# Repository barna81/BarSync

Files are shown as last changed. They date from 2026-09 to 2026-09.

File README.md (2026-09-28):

<picture><source media="(prefers-color-scheme: dark)" srcset="images/BarSync_logo_white.svg"><source media="(prefers-color-scheme: light)" srcset="images/BarSync_logo.svg">BarSync Logo</picture>
<p align="right">
<b>MIDI Clock Bar Counter</b><br/>
<sub><i>-Always in Time.-</i></sub>
</p>
<br clear="left"/>

*[Deutsche Version](README.de.md)*

BarSync is an ESP32-based device that receives an incoming MIDI clock and
displays bar position, beat progress, tempo, and elapsed play time on a
128×64 OLED display.

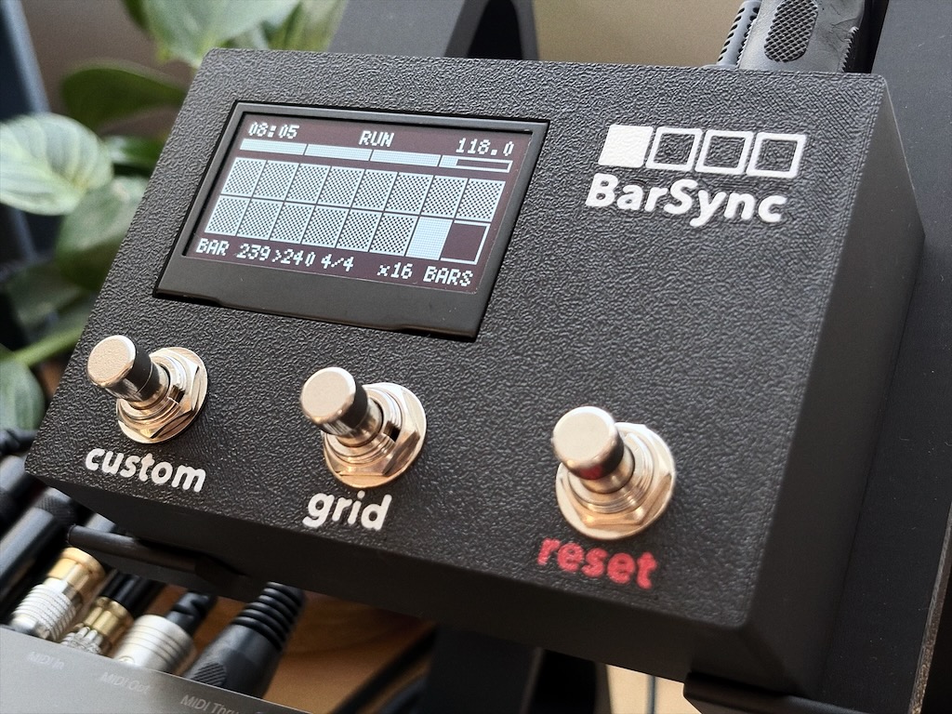
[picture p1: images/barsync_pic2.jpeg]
BarSync


## Status (as of 2026-09-22)

BarSync - Desktop version (this device) 
- Current firmware: 1.3.2  
Improvements: introduced a browser-based firmware flasher — firmware
can now be flashed straight from the browser (Chrome/Edge), no Arduino
IDE needed, see the "Flashing the Firmware" section below; no
functional firmware changes
- Firmware: 1.3.1  
    Improvements: SCROLL mode with a much clearer sense of motion (stripe
    pattern + marker halo), extended bar/playtime counter limits, grid
    counter/BPM detection now keep running seamlessly in the background,
    various button-combo bug fixes
- Firmware: 1.3.0  
    New features: Marker Editor (place your own markers on the bar grid), two grid display modes (CYCLE/SCROLL), End Bar (loop/stop/continue the count at a defined bar)
- Schematic, PCB layout (hardware rev. 1.2), and firmware finished and tested
- PCBs for self-assembly have arrived
- A matching 3D-printable enclosure is available here [`enclosure`](enclosure/)
- A solder-it-yourself kit is being considered, depending on interest

BarSync - Eurorack version (in development, not yet on GitHub)
- Code finished
- PCB layout finished and ordered
- Schematic and PCB layout to follow
- 3D-printable Eurorack frame is in development

*(Interested in the kit or the Eurorack version? Open an issue in this repo or get in touch.)*

---

## What is this?
Never miss the drop...

BarSync keeps you locked into your track's arrangement — live or in the studio. Know exactly where you stand in the bar count, so drops, breaks and builds never catch you off guard.

Since I couldn't find anything similar on the market or in the DIY scene, I built BarSync.
BarSync supports you during your live performance. During a show your hands are usually full, and it's easy to lose track of the timing. No more counting bars in your head to land the drop at the right moment: BarSync counts and visualizes the bars elapsed since a starting point you define yourself. That starting point can be the first MIDI clock signal from your sequencer, or you can reset it at any time with the reset button. This way you always know exactly which bar you're in. The visualization adapts to your needs (1-128 bars can be displayed).

## Features

- Bar/beat counter, synced to the incoming MIDI clock (24 PPQN)
- Grid progress bar (x1 to x128 bars) — overall area stays constant,
  tile size adapts accordingly
- Two grid display modes: CYCLE (repeating cycle) or SCROLL
  (continuous, with markers scrolling into view)
- Marker Editor: place your own markers on the bar grid (4 symbols) —
  for arrangement points, phrase starts, or band cues
- End Bar: automatically loop, stop, or continue the count at a
  defined bar — fixed, or at your last placed marker
- 5 selectable time signatures (2/4, 3/4, 4/4, 5/4, 7/8)
- Reset button: two stages (short = bar end, medium/hold = cycle end) — each independently configurable whether it also resets the elapsed play time (default: yes). Plus a standalone "SET 1.1" function (default custom-button role) to instantly re-anchor the beat pattern, either quantized (rounded to the nearest beat) or instant (raw tick) — selectable in the settings menu
- MIDI Monitor (Note/CC/PC/Pitch Bend log, MIDI clock and RUN/STOP graph) right on the device
- Nudge mode for manually compensating clock phase drift
- MIDI-Thru
- Standby (light sleep) on MIDI inactivity
- On-device settings menu (no app or software required)

## Operation

Quick overview — full guide in
[`docs/BarSync_Quickstart_EN.pdf`](docs/BarSync_Quickstart_EN.pdf):

| Button | Function |
|---|---|
| Custom button (short) | SET 1.1 (re-anchor beat pattern)* |
| Custom button (hold 1s) | Toggle MIDI Monitor** |
| Grid (short) | Change the number of bars shown in the grid (x1–x128) |
| Reset (short/medium) | Reset stage 1/2 |
| Custom button + Grid together | Toggle nudge mode |
| Hold Reset 1s at boot | Settings menu |

*Configurable in setup: custom button for cycling through the time signatures, or SET1.1 (default)  
**In the MIDI Monitor screen, the reset button clears the Note/CC log instead of triggering its normal reset function.

---

## Cool! How do I get one?

If you'd like to build the device yourself, see [LICENSE](LICENSE) — you'll find the corresponding firmware, schematic, and parts list here. I've also designed a PCB, whose layout is included as well. Since it's a fairly simple layout, you can also use perfboard or even a breadboard to build BarSync. Basic knowledge of the ESP32, a soldering iron, and general electronics will be helpful.

In short: the project is currently still in a full DIY stage. Depending on interest, I'm considering offering a BarSync kit. It would come with a 3D-printed enclosure, a PCB, and all the necessary electronic components ready to be assembled. All that would be left to do is soldering and flashing the ESP32.

## Building Your Own

- Full [`schematic`](hardware/kicad/BarSync/BarSync_schematic.pdf)  
- PCB layout, and Gerber files are in [`hardware/`](hardware/)  
- Full bill of materials: [`hardware/BarSync_BOM.en.md`](hardware/BarSync_BOM.en.md)  
- Electronic parts as a ready-made Reichelt cart: [reichelt.de/my/2391791](https://www.reichelt.de/my/2391791)  
- Assembly guide: [`hardware/BarSync_Aufbauanleitung.en.md`](hardware/BarSync_Aufbauanleitung.en.md)  
- 3D-printable enclosure available here: [`enclosure`](enclosure/)

<p align="center">
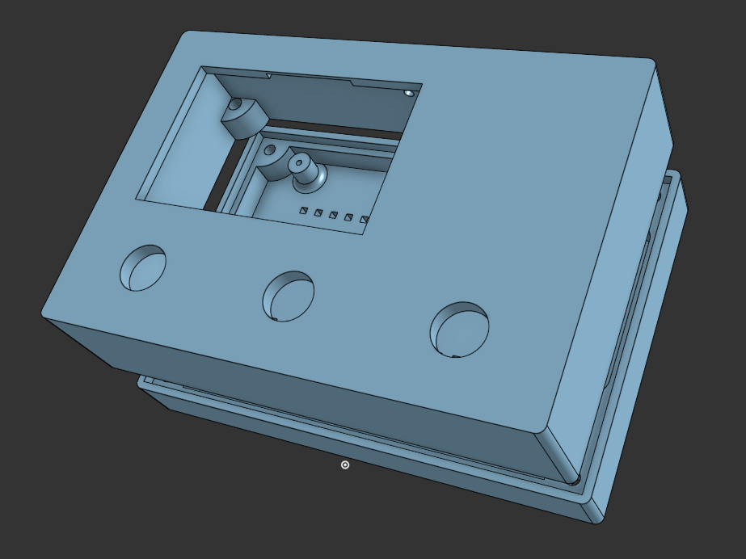
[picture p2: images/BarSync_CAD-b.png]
BarSync_CAD

</p>

## What´s inside?
First build with the new PCB!  

<p align="center">
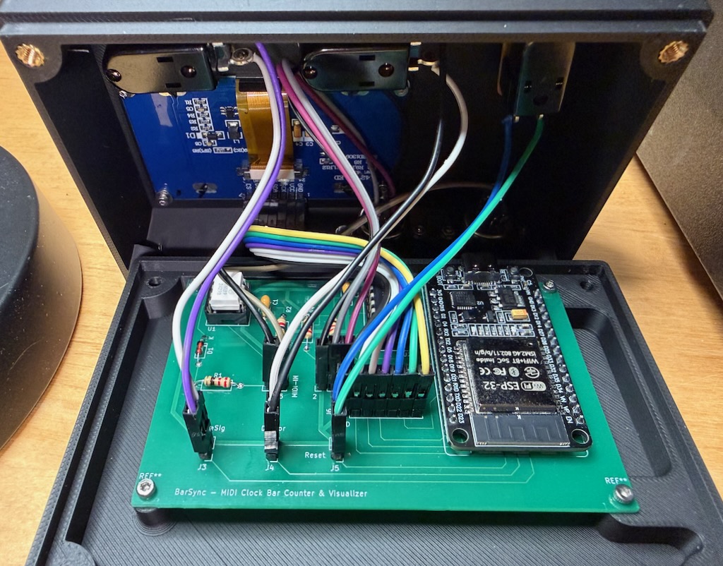
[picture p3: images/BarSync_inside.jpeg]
BarSync_inside

</p>

## Key Hardware

- ESP32 dev board (30-pin DOIT layout)
- SSD1309 OLED, 2.42", 128×64, SPI
- 3 buttons (custom, grid, reset)

## Flashing the Firmware

### 1. Web Flasher (recommended)

Right from your browser, no Arduino IDE, no driver install — works in Chrome or Edge (Windows/macOS/Linux):

**[barna81.github.io/BarSync/flash](https://barna81.github.io/BarSync/flash/)**

### 2. Manual Flashing (Arduino IDE)

For anyone who prefers to compile it themselves, or whose browser doesn't support the web flasher (e.g. Safari, Firefox). Detailed step-by-step instructions incl. USB driver install: see **Chapter 8 "Flash the Firmware"** in the [Assembly Guide](hardware/BarSync_Aufbauanleitung.en.md).

Short version:
1. Install the Arduino IDE, add ESP32 board support
2. Install libraries: [**"MIDI Library"**](https://github.com/FortySevenEffects/arduino_midi_library) (FortySevenEffects), [**"U8g2"**](https://github.com/olikraus/u8g2) (olikraus)
3. Open [`firmware/barsync.ino`](firmware/barsync.ino), select board "ESP32 Dev Module", upload

## License

This project is licensed under **CC BY-NC-SA 4.0** — see [LICENSE](LICENSE).
Free to use, modify, and share for **non-commercial** purposes, with
attribution and share-alike terms. For commercial use, please get in touch.

---

*[Deutsche Version](README.de.md)*

*Built with a lot of debugging, deep MIDI timing analysis, and an
occasional detour into building a Space Invaders clone.*

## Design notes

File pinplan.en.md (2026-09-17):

# Pin Plan — BarSync (ESP32)

*[Deutsche Version](pinplan.md)*

> **Note:** For readability, the PCB header designators (J1–J6) are
> intentionally left out here — this pin plan focuses on the signal logic
> (which signal goes where). For the mapping to the board headers, see
> [`hardware/BarSync_BOM.en.md`](hardware/BarSync_BOM.en.md) and
> [`hardware/BarSync_Aufbauanleitung.en.md`](hardware/BarSync_Aufbauanleitung.en.md).

## 1. Display — SSD1309 2.42" OLED (SPI, 128×64)

**Connection (for kit/PCB version):** The main board carries a
**7-pin header (2.54 mm pitch)** that breaks out the relevant ESP32 pins.
From the display itself, a **7-wire ribbon cable (rainbow cable) with
Dupont sockets on both ends** runs to the header on the board. This lets
the display be mounted mechanically independent of the main board in the
enclosure window (at a different position/height), without any soldering
on the display itself — both ends simply plug in.

| Display Pin | ESP32 Pin | GPIO | Cable Color (ribbon cable) |
|---|---|---|---|
| GND | GND | – | |
| VCC | 3V3 | – | |
| SCK / D0 / CLK | GPIO18 | 18 | |
| SDA / D1 / MOSI | GPIO23 | 23 | |
| RES / RST | GPIO4 | 4 | |
| DC | GPIO21 | 21 | |
| CS | GPIO5 | 5 | |

**Parts list for this connection:**
- 1× 7-pin header, straight, 2.54 mm pitch (soldered onto the main board)
- 1× 7-wire ribbon cable with Dupont female-female connectors,
  length depending on enclosure depth (e.g. 10-15 cm)
- The display keeps its own factory header (male) — no soldering
  needed on the display itself

> Note: If the module has a BS pin/solder jumper for SPI/I2C switching,
> it must be set to **SPI**.

---

## 2. MIDI-IN (Optocoupler Circuit, 6N139)

| Signal | ESP32 Pin | GPIO |
|---|---|---|
| MIDI data (optocoupler output)  | GPIO15 (RX2) | 15 |

MIDI-IN (DIN-5) → 220Ω series resistor (R1) → input LED of U1 (6N139,
pin 2/3). D1 (1N4148) is wired **antiparallel** to the input LED and
protects it against reverse polarity/negative voltage spikes — it
doesn't conduct in normal operation. Output side: Vb (pin 7) via
4.7–10kΩ (R2) to GND, output (pin 6) via a 220Ω pull-up (R3) to +3V3 →
ESP32 GPIO15. Common ground is required on the output side (ESP32,
display, U1 pin 5) — the MIDI input side stays galvanically isolated by
the optocoupler.

Full wiring: [schematic](hardware/kicad/BarSync/BarSync_schematic.pdf),
parts: [`BarSync_BOM.en.md`](hardware/BarSync_BOM.en.md).

> The base resistor at pin 7 (Vb) is important for clean, fast edges with
> MIDI clock (24 PPQN) — without it, clock ticks can be lost or stop
> messages can be misinterpreted.

---

## 3. MIDI-THRU (Buffered Forwarding, 7406/74LS05)

U1 pin 6 (optocoupler output, = same node as GPIO15) feeds a gate input
of U2 (7406/74LS05, hex inverter with open-collector output); its output
drives the THRU socket (pin 5 signal, pin 4 pull-up via a 220Ω resistor
R4 to +5V, pin 2 not connected). Unused gates (5 of 6) are left open or
tied to GND (follow the datasheet recommendation). Uses no ESP32 pin.

Full wiring: [schematic](hardware/kicad/BarSync/BarSync_schematic.pdf).

---

## 4. Buttons

| Function | ESP32 Pin | GPIO | Wiring |
|---|---|---|---|
| Toggle grid | GPIO33 | 33 | Button to GND, INPUT_PULLUP |
| Custom button (freely assignable, currently: SET 1.1) | GPIO32 | 32 | Button to GND, INPUT_PULLUP |
| Reset (short/long) | GPIO25 | 25 | Button to GND, INPUT_PULLUP |

All three buttons (normally-open): one pin to the listed GPIO, the other
pin to GND. (Internal pull-ups are enabled in the code (`INPUT_PULLUP`),
no external resistors needed.)

---

## 5. Overview of All Used ESP32 Pins

| GPIO | Function |
|---|---|
| 4 | OLED RESET |
| 5 | OLED CS |
| 15 | MIDI IN (RX2) |
| 17 | free (not broken out on all boards) |
| 18 | OLED SCK (= VSPI SCK) |
| 19 | free (caution: VSPI default MISO, do not use!) |
| 21 | OLED DC |
| 23 | OLED MOSI |
| 25 | Reset button |
| 32 | Custom button (currently: SET 1.1) |
| 33 | Grid button |
| 3V3  | Display VCC |
| GND  | Display GND, optocoupler GND (common ground!) |

> **INFO: MIDI-Thru does not use any ESP32 pin** — the 7406 buffer is
> connected directly to the optocoupler output node, not to the ESP32
> itself.

---

## Important Notes

1. **Common ground:** ESP32 GND, display GND, and the output side of the
   optocoupler must all be connected together. The MIDI input side (coming
   from the sender) remains galvanically isolated by the optocoupler.
2. **Keep SPI cables short** (SCK/MOSI); under about 15–20 cm is fine.
3. **GPIO15** is used exclusively for MIDI RX here — don't reuse it for
   any other purpose.
4. **Watch the VSPI default pins:** The ESP32's hardware SPI bus (VSPI)
   defaults to SCK=18, MISO=19, MOSI=23, CS=5. GPIO19 (MISO) should NOT be
   used for other signals (e.g. DC), even though the display doesn't need
   MISO — the SPI peripheral/library still configures the pin internally,
   which can cause interference/screen noise. That's why DC is on GPIO21
   here instead of GPIO19.

---

## Current Status: Real KiCad Project (Authoritative Source)

This pin plan still correctly describes the underlying pin logic, but
the **authoritative, verified source** for the schematic and PCB is now
the finished KiCad project `BarSync` (schematic + PCB, fully routed,
DRC-checked, netlist verified multiple times):

- `BarSync.kicad_pro` / `.kicad_sch` / `.kicad_pcb`
- `BarSync.net` (exported netlist)
- Gerber files in [`hardware/kicad/BarSync/gerbers/`](hardware/kicad/BarSync/gerbers/)
- [`Schematic`](hardware/kicad/BarSync/BarSync_schematic.pdf)

> A DRC report and a rendered PCB image aren't currently included in the repo,
> but can be exported directly from KiCad any time (Tools → Run DRC, or
> 3D viewer → export image).

---

*[Deutsche Version](pinplan.md)*

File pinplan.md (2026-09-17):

# Pinplan — BarSync (ESP32)

*[English version](pinplan.en.md)*

> **Hinweis:** Zur besseren Übersicht sind die PCB-Header-Bezeichner (J1–J6)
> hier bewusst weggelassen — dieser Pinplan fokussiert auf die Signal-Logik
> (welches Signal geht wohin). Die Zuordnung zu den Board-Headern findest du
> in [`hardware/BarSync_BOM.md`](hardware/BarSync_BOM.md) und
> [`hardware/BarSync_Aufbauanleitung.md`](hardware/BarSync_Aufbauanleitung.md).

## 1. Display — SSD1309 2,42" OLED (SPI, 128×64)

**Anbindung (für Bausatz/PCB-Version):** Auf der Hauptplatine sitzt eine
**7-polige Stiftleiste (2,54mm-Raster)**, die die relevanten ESP32-Pins
herausführt. Vom Display selbst geht ein **7-adriges Flachbandkabel
(Rainbow-Kabel) mit Dupont-Buchsen an beiden Enden** zur Stiftleiste auf
der Platine. Dadurch kann das Display mechanisch unabhängig von der
Hauptplatine im Gehäusefenster montiert werden (andere Position/Höhe),
ohne dass am Display selbst gelötet werden muss — beide Seiten sind
steckbar.

| Display-Pin | ESP32 Pin | GPIO | Kabelfarbe (Flachbandkabel) |
|---|---|---|---|
| GND | GND | – | |
| VCC | 3V3 | – | |
| SCK / D0 / CLK | GPIO18 | 18 | |
| SDA / D1 / MOSI | GPIO23 | 23 | |
| RES / RST | GPIO4 | 4 | |
| DC | GPIO21 | 21 | |
| CS | GPIO5 | 5 | |

**Stückliste für diese Verbindung:**
- 1× 7-polige Stiftleiste, gerade, 2,54mm-Raster (auf der Hauptplatine
  eingelötet)
- 1× 7-adriges Flachbandkabel mit Dupont-Buchse-Buchse-Anschlüssen
  (female-female), Länge je nach Gehäusetiefe (z. B. 10-15cm)
- Display selbst behält seine eigene, werkseitige Stiftleiste (male) —
  keine Lötarbeit am Display nötig

> Hinweis: Falls das Modul einen BS-Pin/Lötjumper für SPI/I2C-Umschaltung hat,
> muss dieser auf **SPI** stehen.

---

## 2. MIDI-IN (Optokoppler-Schaltung, 6N139)

| Signal | ESP32 Pin | GPIO |
|---|---|---|
| MIDI-Daten (Optokoppler-Ausgang) | GPIO15 (RX2) | 15 |

MIDI-IN (DIN-5) → 220Ω-Vorwiderstand (R1) → Eingangs-LED von U1 (6N139,
Pin 2/3). D1 (1N4148) liegt **antiparallel** zur Eingangs-LED und schützt
sie vor Verpolung/negativen Spannungsspitzen — leitet im Normalbetrieb
nicht mit. Ausgangsseite: Vb (Pin 7) über 4,7–10kΩ (R2) nach GND, Ausgang
(Pin 6) über 220Ω-Pull-up (R3) nach +3V3 → ESP32 GPIO15. Gemeinsame Masse
zwingend auf der Ausgangsseite (ESP32, Display, U1 Pin 5) — die
MIDI-Eingangsseite bleibt durch den Optokoppler galvanisch getrennt.

Vollständige Beschaltung: [Schaltplan](hardware/kicad/BarSync/BarSync_schematic.pdf),
Bauteile: [`BarSync_BOM.md`](hardware/BarSync_BOM.md).

> Der Basiswiderstand an Pin 7 (Vb) ist wichtig für saubere, schnelle
> Flanken bei MIDI-Clock (24 PPQN) — ohne ihn können Clock-Ticks verloren
> gehen oder Stop-Nachrichten fehlerhaft interpretiert werden.

---

## 3. MIDI-THRU (gepufferte Weiterleitung, 7406/74LS05)

U1 Pin 6 (Optokoppler-Ausgang, = derselbe Knoten wie GPIO15) speist einen
Gate-Eingang von U2 (7406/74LS05, Hex-Inverter mit Open-Kollektor-Ausgang);
dessen Ausgang treibt über einen 220Ω-Pull-up (R4, nach +5V) die
THRU-Buchse (Pin 5 Signal, Pin 4 Pull-up, Pin 2 nicht verbunden).
Ungenutzte Gates (5 von 6) bleiben offen oder auf GND (Datenblatt-
Empfehlung beachten). Belegt keinen ESP32-Pin.

Vollständige Beschaltung: [Schaltplan](hardware/kicad/BarSync/BarSync_schematic.pdf).

---

## 4. Taster

| Funktion | ESP32 Pin | GPIO | Beschaltung |
|---|---|---|---|
| Grid umschalten | GPIO33  | 33 | Taster gegen GND, INPUT_PULLUP  |
| Custom-Taster (frei belegbar, aktuell: SET 1.1) | GPIO32  | 32 | Taster gegen GND, INPUT_PULLUP  |
| Reset (kurz/mittel) | GPIO25  | 25 | Taster gegen GND, INPUT_PULLUP  |

Alle drei Taster (Schließer): ein Pin an den genannten GPIO, der andere Pin an GND.
(Interne Pull-ups werden sind im Code aktiviert (`INPUT_PULLUP`), keine externen
Widerstände nötig.)

---

## 5. Übersicht aller belegten ESP32-Pins

| GPIO | Funktion |
|---|---|
| 4 | OLED RESET |
| 5 | OLED CS |
| 15 | MIDI IN (RX2) |
| 17 | frei (nicht auf allen Boards herausgeführt) |
| 18 | OLED SCK (= VSPI SCK)|
| 19 | frei (Vorsicht: VSPI-Standard-MISO, nicht belegen!) |
| 21 | OLED DC |
| 23 | OLED MOSI |
| 25 | Taster Reset |
| 32 | Custom-Taster (aktuell: SET 1.1) |
| 33 | Taster Grid |
| 3V3  | Display VCC |
| GND  | Display GND, Optokoppler GND (gemeinsame Masse!) |

> **INFO: MIDI-Thru belegt keinen ESP32-Pin** — der 7406-Puffer hängt direkt am
> Optokoppler-Ausgangsknoten, nicht am ESP32 selbst.

---

## Wichtige Hinweise

1. **Gemeinsame Masse:** ESP32-GND, Display-GND und die Ausgangsseite des
   Optokopplers müssen alle miteinander verbunden sein. Die MIDI-Eingangsseite
   (vom Sender kommend) bleibt durch den Optokoppler galvanisch getrennt.
2. **Kurze Kabel bei SPI** (SCK/MOSI), unter ca. 15–20 cm ist unproblematisch.
3. **GPIO15** wird hier exklusiv für MIDI-RX genutzt — nicht zusätzlich für
   andere Zwecke belegen.
4. **VSPI-Standardpins beachten:** Der ESP32-Hardware-SPI-Bus (VSPI) belegt
   standardmäßig SCK=18, MISO=19, MOSI=23, CS=5. GPIO19 (MISO) sollte NICHT
   für andere Signale (z. B. DC) verwendet werden, auch wenn das Display
   MISO nicht braucht — die SPI-Peripherie/Bibliothek konfiguriert den Pin
   trotzdem intern, was zu Störungen/Bildrauschen führen kann. Deshalb liegt
   DC hier auf GPIO21 statt GPIO19.

---

## Aktueller Stand: echtes KiCad-Projekt (autoritative Quelle)

Dieser Pinplan beschreibt weiterhin korrekt die grundsätzliche Pin-Logik,
aber die **verbindliche, geprüfte Quelle** für Schaltplan und Platine ist
jetzt das fertige KiCad-Projekt `BarSync` (Schaltplan + PCB,
vollständig geroutet, DRC-geprüft, Netzliste mehrfach verifiziert):

- `BarSync.kicad_pro` / `.kicad_sch` / `.kicad_pcb`
- `BarSync.net` (exportierte Netzliste)
- Gerber-Dateien in [`hardware/kicad/BarSync/gerbers/`](hardware/kicad/BarSync/gerbers/)
- [`Schaltplan`](hardware/kicad/BarSync/BarSync_schematic.pdf)

> Ein DRC-Report und ein gerendertes Platinenbild liegen aktuell nicht im Repo,
> lassen sich bei Bedarf aber jederzeit direkt aus KiCad exportieren
> (Werkzeuge → DRC-Prüfung durchführen bzw. 3D-Ansicht → Bild exportieren).

---

*[English version](pinplan.en.md)*

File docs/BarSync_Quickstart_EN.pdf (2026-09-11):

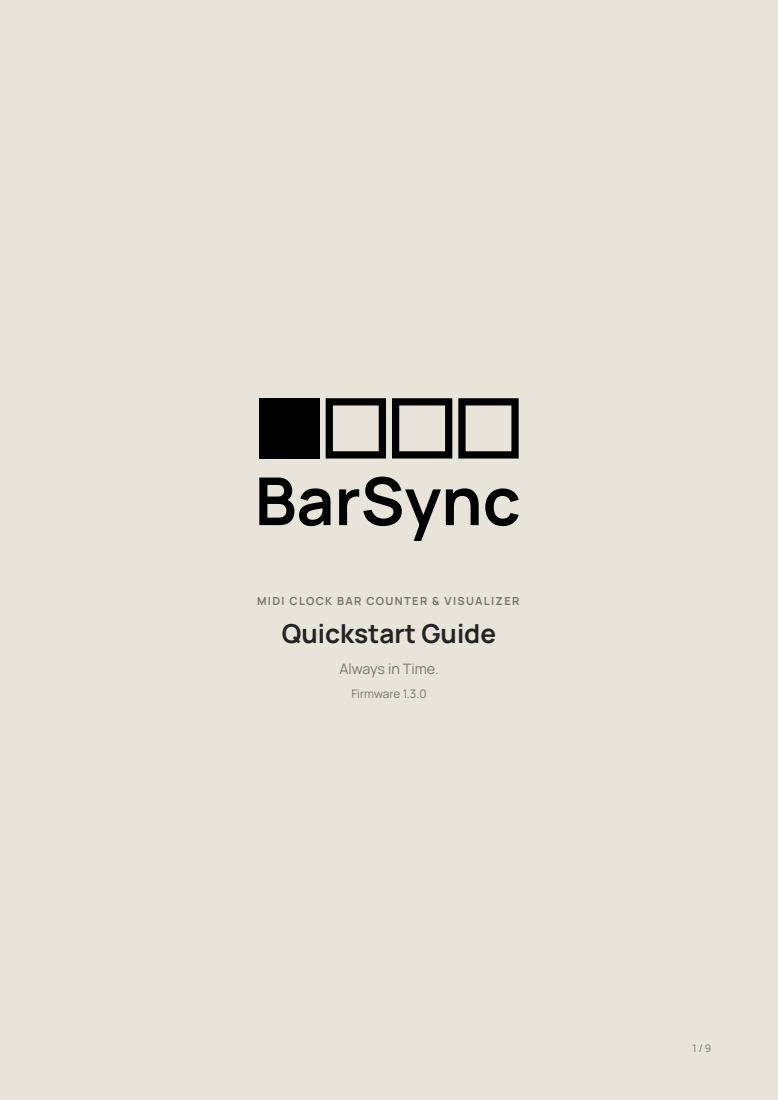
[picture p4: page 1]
M I D I C L O C K B A R C O U N T E R & V I S UA L I Z E R Quickstart Guide

Always in Time.
Firmware 1.3.0

OV E R V I E W

## What is BarSync?

BarSync keeps you on top of your track's arrangement — live or in the studio. It receives your sequencer's MIDI clock and counts and visualizes the bars elapsed since a starting point you define yourself — either the first MIDI clock signal, or a manual reset via button. That way you always know exactly which bar you're in, and drops, breaks and builds never catch you off guard.

Features

Bar/beat counter, synced to the incoming MIDI clock (24 PPQN)

Grid progress bar (x1 to x128 bars) — footprint stays constant, tile size adapts automatically

Two grid display modes: CYCLE (repeating cycle) or SCROLL (continuous, with markers scrolling into view)

Marker Editor: place your own markers on the bar grid (4 symbols) — for arrangement points, phrase starts, or band cues

End Bar: automatically loop, stop, or continue the count at a defined bar — fixed, or at your last placed marker

5 selectable time signatures (3/4, 4/4, 5/4, 6/8, 7/8)

Reset button with two stages (bar end / cycle end), plus a standalone SET 1.1 function to instantly lay down a new beatgrid (quantized or instant)

MIDI Monitor built into the device (Note/CC/PC/Pitch-Bend log, MIDI clock and RUN/STOP graph)

Nudge mode to manually compensate for clock phase drift

MIDI Thru to pass the signal on to further devices

Standby (light sleep) on MIDI inactivity

Full settings menu right on the device — no app, no software needed

BarSync — Always in Time. | 2 / 9

G E T T I N G S T A R T E D

## Connection & First Start

If no MIDI clock arrives for a while, the display shows "NO MIDI-CLOCK" instead — a cue to check your MIDI cable and source (see Troubleshooting on the last page).

Connect your MIDI source.
Connect your sequencer's/DAW interface's MIDI OUT to BarSync's MIDI IN.

1

Optional: pass it on.
MIDI THRU lets you forward the incoming signal unchanged to another device — handy when BarSync sits in the middle of an existing MIDI chain.

2

Power it up.
BarSync starts automatically and shows the retro-style boot screen for about 5 seconds.

3

Start the MIDI clock.
As soon as your sequencer is running, the status switches from STOP to RUN, and the bar/beat counter starts running.

4

Set a reference point (optional).
The 1.1 is set automatically as soon as BarSync receives your sequencer's Start/Run signal — you don't have to do anything for that. If you'd rather start counting from a specific point instead, just press the Reset button.

5

O P E R AT I O N

## The Three Buttons

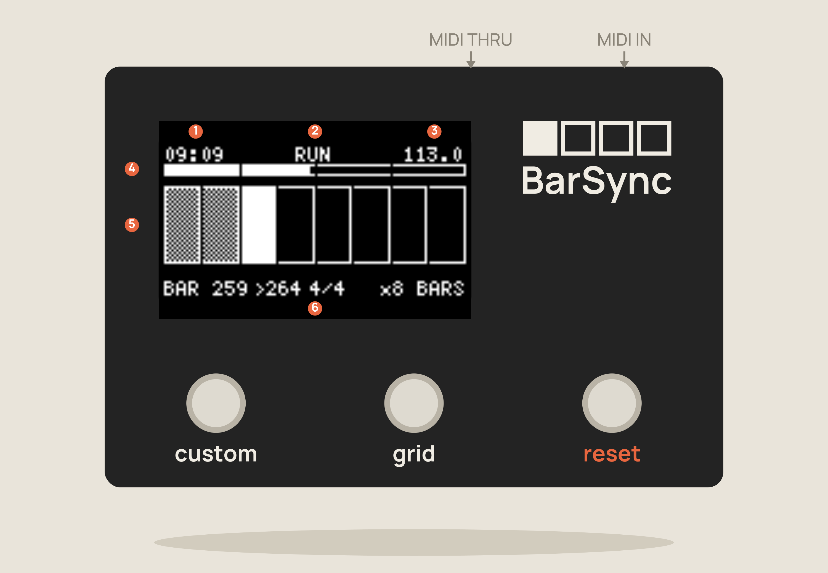
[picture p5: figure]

The Display at a Glance

NO. | SHOWS

### 1 Play time (mm:ss) since the last start/reset

### 2 Status — RUN or STOP

### 3 Tempo in BPM

### 4 Progress within the current bar

### 5 Progress within the current grid cycle — one tile = one bar

### 6 current bar, end of cycle, time signature, grid size

custom

Short press: SET 1.1 — instantly lays down a new beatgrid (default assignment).
Hold 1 second: toggle MIDI Monitor on/off.
Together with Grid: toggle Nudge mode on/off.
Together with Reset (hold 1s): opens OPERATION SETUP (grid mode, marker editor, end bar).

grid

Short press: cycles the number of bars shown in the grid (x1 to x128).

reset

Short press (Reset 1): waits for the end of the current bar.
Hold (Reset 2): waits for the end of the current grid cycle.
Hold 1 second while booting: opens the settings menu.
On the MIDI Monitor screen: clears the note/CC list instead.

The Custom button is freely assignable — the functions shown here match the firmware default (Switches > Custom > Function).

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
O P E R AT I O N I N D E T A I L

## Reset vs. SET 1.1 — What's the Difference?

The 1.1 is set all by itself to begin with: as soon as BarSync receives your sequencer's Start/Run signal, counting starts automatically at 1.1 — without you pressing any button.

You only need SET 1.1 when you want to correct that automatically-set point afterwards — for example when you've started a new song during your live set and your track's 1.1 no longer "sits" on BarSync's 1.1. Sure, you could restart the sequencer and everything would line up again. But during a performance that's obviously something you'd rather avoid. That's where SET 1.1 comes in: pressing the Custom button lays down a new beatgrid with 1.1 exactly at that moment.

The two Reset stages (1 and 2) build directly on that beatgrid and simply reset the bar counter including the grid (and, depending on settings, the play time) — always in sync with the current beatgrid.

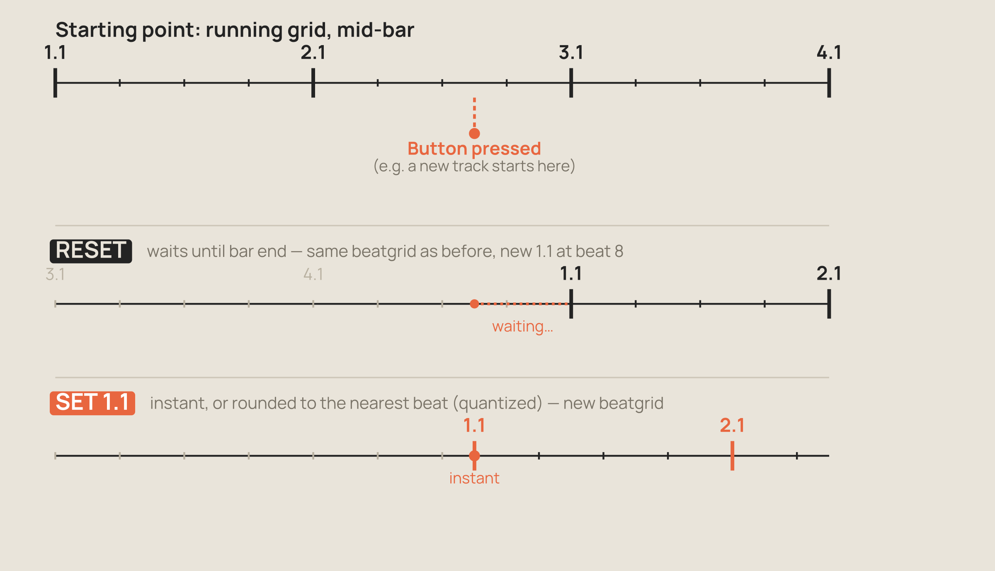
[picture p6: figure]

FUNCTION | EFFECT
Reset | Waits for the end of the current bar (Reset 1) or cycle (Reset 2) and then resets to 1.1. The beatgrid stays unchanged — the new bar boundaries land exactly where a bar boundary already was.
SET 1.1 | Lays down a completely new beatgrid instantly (Instant) or rounded to the nearest beat (Quantized) — regardless of where the previous beatgrid sat. As a result, every following bar boundary can shift compared to before.

Rule of thumb: if your set runs continuously within the same beatgrid, Reset is all you need. Only once a new song section starts with its own downbeat that doesn't match your current count do you need SET 1.1 to re-anchor the beatgrid.

C O N F I G U R AT I O N

## Device Setup

Open it: hold the Reset button for 1 second while powering on.

SETUP
TIMESIG — time signature, direct value (3/4, 4/4, 5/4, 6/8, 7/8), default 4/4
SWITCHES >
CUSTOM > Function (Timesig / SET 1.1) — depending on Function, underneath: time-signature selection or Mode (Quantized/Instant)
GRID > choice of which divisor steps are selectable
RESET > playtime reset per stage (Yes/No)
DISPLAY >
CONTRAST, INVERT (swap black/white), GRID LINES (separators every 32 bars, toggleable) STANDBY — on/off, sleep delay
DEFAULTS — load factory settings (with confirmation)

Navigating the Menu

BUT TON | FUNCTION IN THE MENU
Custom | move up one line
Grid | move down one line
Reset (short) | open selection / change value
Reset (hold 1s) | back one level
Reset (on page 1, hold 3s) | save, exit menu, restart

C O N F I G U R AT I O N

## Operation Setup

Open/exit it: hold Custom + Reset together for 1 second — during normal operation, not while booting. Holding the same combo again exits the menu from any screen inside it and saves automatically.

OPERATION SETUP
GRID MODE — CYCLE (repeating cycle) or SCROLL (continuous, markers scroll in from the right)
SET MARKERS — opens the marker editor, see below
END BAR — OFF / LAST MARKER / MANUAL
END BAR ACT — LOOP / STOP / CONTINUE (only shown when END BAR ≠ OFF)

Navigating the Menu

BUT TON | FUNCTION IN THE MENU
Custom | move up one line
Grid | move down one line
Reset (short) | select the row / toggle its value (GRID MODE, END BAR, END BAR ACT directly; with END BAR =
MANUAL a BAR NUMBER row also appears)

Reset (hold 1s) back one level

Placing Markers (SET MARKERS)
The marker editor lets you tag individual bars with one of four symbols — e.g. for arrangement points, phrase starts, or band cues. It temporarily replaces the beat bar with two navigation arrows.
BUT TON | FUNCTION IN THE MARKER EDITOR
Custom | move the cursor back one bar (left arrow only shown when possible)
Grid | move the cursor forward one bar (right arrow only shown when possible)
Custom/Grid (hold >1s) | fast-page in steps of 16 bars; Custom and Grid are interlocked — only one direction at a
time
Custom + Grid together | cycles the tool: square → circle → triangle → X → DEL (delete)
Reset (short) | places the marker with the current tool at the cursor — or erases it when the tool is DEL
Custom + Reset (hold 1s) | exits the editor, saves, and returns to OPERATION SETUP

Display at the bottom: current bar on the left (with a blinking cycle-end number), number of placed markers on the right (out of a max. of 500), the current tool, and a "RESET = PLACE" / "RESET = DELETE" hint in the middle.

D I A G N O S T I C S

## MIDI Monitor

The built-in MIDI Monitor shows you, right on the device, what's actually arriving on the MIDI line — handy for debugging your setup without any separate software or a computer sitting next to you.

Show/Hide
Hold the Custom button for 1 second (default assignment).

What's Shown?

On the Monitor screen, the Reset button takes on a different job: it clears the note/CC list instead of triggering the normal reset function.

If no MIDI clock arrives for more than 5 seconds, "NO CLOCK" blinks in place of the clock graph instead.

Event log of the last 6 Note On/Note Off, CC, Program Change and Pitch Bend messages, including channel — newest message on top

MIDI clock graph: one spike per detected beat, the downbeat (1.1) drawn twice as wide as a regular beat

MIDI RUN/STOP trace as a level graph, with a plain-text "RUN = HIGH" / "RUN = LOW" status

R E F E R E N C E

## Troubleshooting & Quick Reference

PROBLEM | SOLUTION
Display stays dark | Check power supply; check contrast in the setup menu (Display >
| Contrast)
"NO MIDI-CLOCK" is shown | Check the MIDI cable and source; make sure the clock is actually running

Buttons don't respond / respond
incorrectly | Restart the device; if in doubt, load factory settings (Setup > Defaults)
Device only responds after a delay following a long pause | Normal behavior: BarSync goes into standby (light sleep) on MIDI inactivity
| and wakes automatically on new activity

Quick Reference

BUT TON | FUNCTION
Custom (short) | SET 1.1 — lay down a new beatgrid*
Custom (hold 1s) | toggle MIDI Monitor on/off*
Grid (short) | cycle the number of bars shown (x1–x128)
Reset (short/hold) | Reset stage 1/2
Custom + Grid | toggle Nudge mode on/off*
Hold Reset while booting | settings menu

*The Custom button is freely assignable — this reflects the firmware default.

Full documentation, schematic, firmware and 3D-printable enclosure: github.com/barna81/BarSync

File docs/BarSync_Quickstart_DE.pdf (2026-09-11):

M I D I C L O C K B A R C O U N T E R & V I S UA L I Z E R Quickstart Guide

Always in Time.
Firmware 1.3.0

Ü B E R B L I C K

## Was ist BarSync?

Mit BarSync behältst du live oder im Studio jederzeit den Überblick über das Arrangement deines Tracks. BarSync empfängt die MIDI-Clock deines Sequencers und zählt und visualisiert die verstrichenen Takte seit einem Startpunkt, den du selbst festlegst — entweder das erste MIDI-Clock-Signal, oder ein manueller Reset per Taster. So weißt du immer genau, in welchem Takt du dich befindest, und Drops, Breaks und Builds treffen nie unvorbereitet auf dich.

Features

Bar-/Beat-Zähler, synchron zur eingehenden MIDI-Clock (24 PPQN)

Grid-Fortschrittsbalken (x1 bis x128 Bars) — Grundfläche bleibt konstant, Kachelgröße passt sich automatisch an

Zwei Grid-Darstellungsmodi: CYCLE (wiederholender Zyklus) oder SCROLL (fortlaufend, mit erkennbaren Markern)

Marker-Editor: eigene Marker im Bar-Grid setzen (4 Symbole) — für Arrangement-Punkte, Phrasenanfänge oder Band-Cues

End Bar: Zählung bei einem definierten Takt automatisch loopen, stoppen oder weiterlaufen lassen — fest oder am letzten gesetzten Marker

5 wählbare Taktarten (3/4, 4/4, 5/4, 6/8, 7/8)

Reset-Taster mit zwei Stufen (Taktende / Zyklusende), zusätzlich eine eigenständige SET 1.1-Funktion zum sofortigen Neuanlegen eines Beatgrids (quantisiert oder instant)

MIDI Monitor direkt am Gerät (Note/CC/PC/Pitch-Bend-Log, MIDI-Clock- und RUN/STOP-Graph)

Nudge-Modus zum manuellen Ausgleich von Clock-Phasendrift

MIDI-Thru zum Weiterschleifen an weitere Geräte

Standby (Light Sleep) bei MIDI-Inaktivität

Komplettes Einstellungsmenü direkt am Gerät — keine App, keine Software nötig

BarSync — Always in Time. | 2 / 9

E R S T E S C H R I T T E

## Anschluss & Erster Start

Kommt länger keine MIDI-Clock an, zeigt das Display stattdessen „NO MIDI-CLOCK" — ein Hinweis, MIDI-Kabel und Quelle zu prüfen (siehe Troubleshooting auf der letzten Seite).

MIDI-Quelle anschließen.
Verbinde den MIDI-OUT deines Sequencers/deiner DAW-Schnittstelle mit dem MIDI IN von BarSync.

1

Optional: weiterschleifen.
Über MIDI THRU kannst du das eingehende Signal unverändert an ein weiteres Gerät weiterreichen — praktisch, wenn BarSync mitten in einer bestehenden MIDI-Kette hängt.

2

Stromversorgung herstellen.
BarSync startet automatisch und zeigt für ca. 5 Sekunden den Boot-Screen im Retro-Stil.

3

MIDI-Clock starten.
Sobald dein Sequencer läuft, wechselt die Statusanzeige von STOP auf RUN, und der Bar-/Beat-Zähler beginnt zu laufen.

4

Referenzpunkt setzen (optional).
Die 1.1 wird automatisch gesetzt, sobald BarSync das Start/Run-Signal deines Sequencers empfängt — du musst dafür nichts tun. Willst du stattdessen ab einer bestimmten Stelle neu zählen, drücke einfach den Reset-Taster.

5

B E D I E N U N G

## Die drei Taster


Das Display im Überblick

NR. | ZEIGT

### 1 Spielzeit (mm:ss) seit dem letzten Start/Reset

### 2 Status — RUN oder STOP

### 3 Tempo in BPM

### 4 Fortschritt innerhalb des aktuellen Takts

### 5 Fortschritt im aktuellen Grid-Zyklus — eine Kachel = ein Takt

### 6 aktueller Takt, Ende des Zyklus, Taktart, Grid-Größe

custom

Kurz drücken: SET 1.1 — legt sofort ein neues Beatgrid an (Default-Belegung).
1 Sekunde halten: MIDI Monitor ein-/ausblenden.
Zusammen mit Grid: Nudge-Modus ein-/ausschalten.
Zusammen mit Reset (1s halten): öffnet OPERATION SETUP (Grid-Modus, Marker-Editor, End Bar).

grid

Kurz drücken: wechselt die Anzahl der im Grid angezeigten Bars (x1 bis x128).

reset

Kurz drücken (Reset 1): wartet auf das Ende des aktuellen Takts.
Halten (Reset 2): wartet auf das Ende des aktuellen Grid-Zyklus.
Beim Booten 1 Sekunde halten: öffnet das Einstellungsmenü.
Im MIDI-Monitor-Screen: löscht stattdessen die Note/CC-Liste.

Der Custom-Taster ist frei belegbar — die hier gezeigten Funktionen entsprechen der Firmware-Voreinstellung (Switches > Custom > Function).

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
B E D I E N U N G I M D E T A I L

## Reset vs. SET 1.1 — was ist der Unterschied?

Die 1.1 wird zunächst ganz von selbst gesetzt: Sobald BarSync das Start/Run-Signal deines Sequencers empfängt, beginnt die Zählung automatisch bei 1.1 — ohne dass du einen Taster drücken musst.

SET 1.1 brauchst du nur, wenn du diesen automatisch gesetzten Punkt nachträglich korrigieren willst — zum Beispiel wenn du während deines Livesets einen neuen Song gestartet hast und die 1.1 deines Tracks nicht mehr auf der 1.1 des BarSync „sitzt". Natürlich könntest du jetzt den Sequencer neu starten, dann wäre alles wieder synchron. Aber während einer Performance möchte man das natürlich vermeiden. Hier kommt SET 1.1 ins Spiel: Ein Druck auf den Custom-Taster erzeugt ein neues Beatgrid mit der 1.1 genau in diesem Moment.

Die beiden Reset-Stufen (1 und 2) bauen genau auf diesem Beatgrid auf und setzen lediglich den Barzähler inkl. Grid (und je nach Einstellung auch die Playtime) zurück — stets in Sync mit dem laufenden Beatgrid.

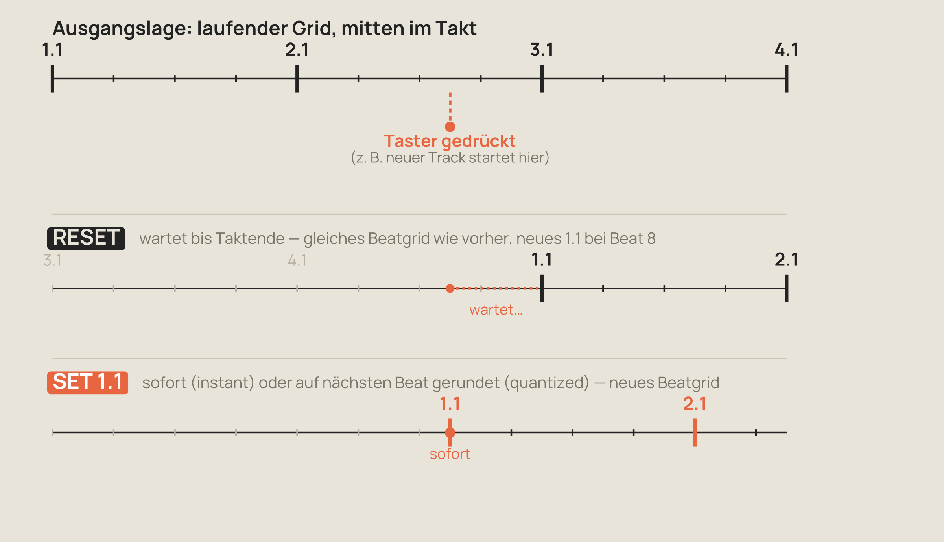
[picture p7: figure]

FUNKTION | WIRKUNG
Reset | Wartet auf das Ende des aktuellen Takts (Reset 1) bzw. Zyklus (Reset 2) und setzt dann auf 1.1 zurück. Das Beatgrid bleibt unverändert — die neuen Taktgrenzen fallen exakt dorthin, wo ohnehin schon eine Taktgrenze war.
SET 1.1 | Legt sofort (Instant) oder auf den nächsten Beat gerundet (Quantized) ein komplett neues Beatgrid an — unabhängig davon, wo das bisherige Beatgrid lag. Dadurch können sich alle folgenden Taktgrenzen gegenüber vorher verschieben.

Faustregel: Läuft dein Set durchgehend im selben Beatgrid, reicht Reset. Erst wenn ein neuer Song-Teil mit eigenem Downbeat einsetzt, der nicht zur bisherigen Zählung passt, brauchst du SET 1.1, um das Beatgrid neu zu verankern.

KO N F I G U R AT I O N

## Device Setup

Öffnen: Reset-Taster beim Einschalten 1 Sekunde gedrückt halten.

SETUP
TIMESIG — Taktart direkt wählbar (3/4, 4/4, 5/4, 6/8, 7/8), Default 4/4
SWITCHES >
CUSTOM > Function (Timesig / SET 1.1) — je nach Function darunter: Timesig-Auswahl oder Mode (Quantized/Instant)
GRID > Auswahl der wählbaren Divisor-Stufen
RESET > Playtime-Reset pro Stufe (Ja/Nein)
DISPLAY >
CONTRAST, INVERT (Schwarz/Weiß tauschen), GRID LINES (Trennlinien alle 32 Bars, abschaltbar) STANDBY — Ein/Aus, Einschlafzeit
DEFAULTS — Werkseinstellungen laden (mit Bestätigung)

Navigation im Menü

TASTE | FUNKTION IM MENÜ
Custom | eine Zeile nach oben
Grid | eine Zeile nach unten
Reset (kurz) | Auswahl öffnen / Wert ändern
Reset (1s halten) | eine Ebene zurück
Reset (auf Seite 1, 3s halten) | speichern, Menü verlassen, Neustart

KO N F I G U R AT I O N

## Operation Setup

Öffnen/Verlassen: Custom + Reset zusammen 1 Sekunde halten — im laufenden Betrieb, nicht beim Booten. Dieselbe Kombination erneut gehalten verlässt das Menü wieder (von jedem Bildschirm darin aus) und speichert automatisch.

OPERATION SETUP
GRID MODE — CYCLE (wiederholender Zyklus) oder SCROLL (fortlaufend, Marker laufen von rechts ein)
SET MARKERS — öffnet den Marker-Editor, siehe unten
END BAR — OFF / LAST MARKER / MANUAL
END BAR ACT — LOOP / STOP / CONTINUE (nur sichtbar, wenn END BAR ≠ OFF)

Navigation im Menü

TASTE | FUNKTION IM MENÜ
Custom | eine Zeile nach oben
Grid | eine Zeile nach unten
Reset (kurz) | Zeile auswählen bzw. Wert umschalten (GRID MODE, END BAR, END BAR ACT direkt; bei END BAR
= MANUAL erscheint zusätzlich die Zeile BAR NUMBER)

Reset (1s halten) eine Ebene zurück

Marker setzen (SET MARKERS)
Im Marker-Editor lassen sich einzelne Takte mit einem von vier Symbolen markieren — z. B. für Arrangement-Punkte, Phrasenanfänge oder Band-Cues. Der Editor ersetzt vorübergehend den Taktbalken durch zwei Navigationspfeile.
TASTE | FUNKTION IM MARKER-EDITOR
Custom | Cursor einen Takt zurück (Pfeil links nur sichtbar, wenn möglich)
Grid | Cursor einen Takt vor (Pfeil rechts nur sichtbar, wenn möglich)
Custom/Grid (>1s halten) | schnelles Blättern in 16er-Schritten; Custom und Grid sind gegeneinander verriegelt
— nur eine Richtung gleichzeitig
Custom + Grid gleichzeitig | wechselt das Werkzeug: Quadrat → Kreis → Dreieck → X → DEL (Löschen)
Reset (kurz) | setzt den Marker mit dem aktuellen Werkzeug am Cursor — bzw. löscht ihn bei
Werkzeug DEL

Custom + Reset (1s halten) verlässt den Editor, speichert und kehrt zu OPERATION SETUP zurück

Anzeige unten: aktueller Takt links (mit blinkender Zyklus-Ende-Zahl), Anzahl gesetzter Marker rechts (von max. 500), aktuelles Werkzeug sowie der Hinweis „RESET = PLACE\" bzw. „RESET = DELETE\" mittig.

D I A G N O S E

## MIDI Monitor

Der eingebaute MIDI Monitor zeigt dir direkt am Gerät, was auf der MIDI-Leitung tatsächlich ankommt — praktisch, um dein Setup zu debuggen, ganz ohne separate Software oder einen Rechner danebenstehen zu haben.

Ein-/Ausblenden
Custom-Taster 1 Sekunde halten (Default-Belegung).

Was wird angezeigt?

Im Monitor-Screen übernimmt der Reset-Taster eine andere Aufgabe: Er löscht die Note/CC-Liste, statt die normale Reset-Funktion auszulösen.

Kommt länger als 5 Sekunden keine MIDI-Clock an, blinkt an der Stelle des Clock-Graphs stattdessen „NO CLOCK".

Event-Log der letzten 6 Note-On/Note-Off-, CC-, Program-Change- und Pitch-Bend-Nachrichten, inkl. Kanal — neueste Nachricht oben

MIDI-Clock-Graph: ein Ausschlag pro erkanntem Beat, der Downbeat (1.1) doppelt so breit wie ein normaler Beat

MIDI-RUN/STOP-Verlauf als Pegel-Trace, mit Klartext-Status „RUN = HIGH" / „RUN = LOW"

R E F E R E N Z

## Troubleshooting & Kurzreferenz

PROBLEM | LÖSUNG
Display bleibt dunkel | Stromversorgung prüfen; Kontrast im Setup-Menü prüfen (Display > Contrast)

„NO MIDI-CLOCK" wird
angezeigt | MIDI-Kabel und -Quelle prüfen; sicherstellen, dass die Clock tatsächlich läuft
Taster reagieren nicht/falsch | Gerät neu starten; im Zweifel Werkseinstellungen laden (Setup > Defaults)
Gerät reagiert erst verzögert nach längerer Pause | Normalverhalten: BarSync geht bei MIDI-Inaktivität in Standby (Light Sleep) und
| wacht bei neuer Aktivität automatisch wieder auf

Kurzreferenz

TASTE | FUNKTION
Custom (kurz) | SET 1.1 — neues Beatgrid anlegen*
Custom (1s halten) | MIDI Monitor ein/aus*
Grid (kurz) | Anzahl der angezeigten Bars wechseln (x1–x128)
Reset (kurz/halten) | Reset-Stufe 1/2
Custom + Grid | Nudge-Modus ein/aus*
Reset beim Booten 1s halten | Einstellungsmenü

*Custom-Taster ist frei belegbar — Angaben entsprechen der Firmware-Voreinstellung.

Vollständige Dokumentation, Schaltplan, Firmware und 3D-druckbares Gehäuse: github.com/barna81/BarSync

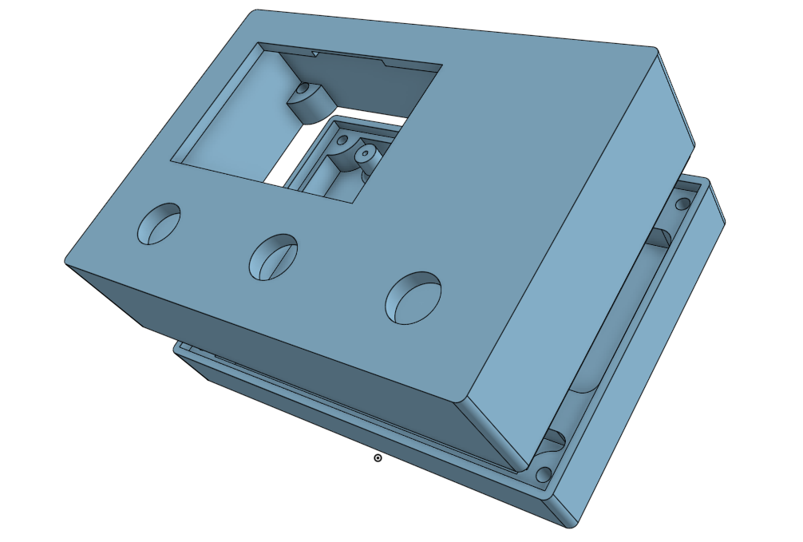
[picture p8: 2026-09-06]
images/BarSync_CAD.png

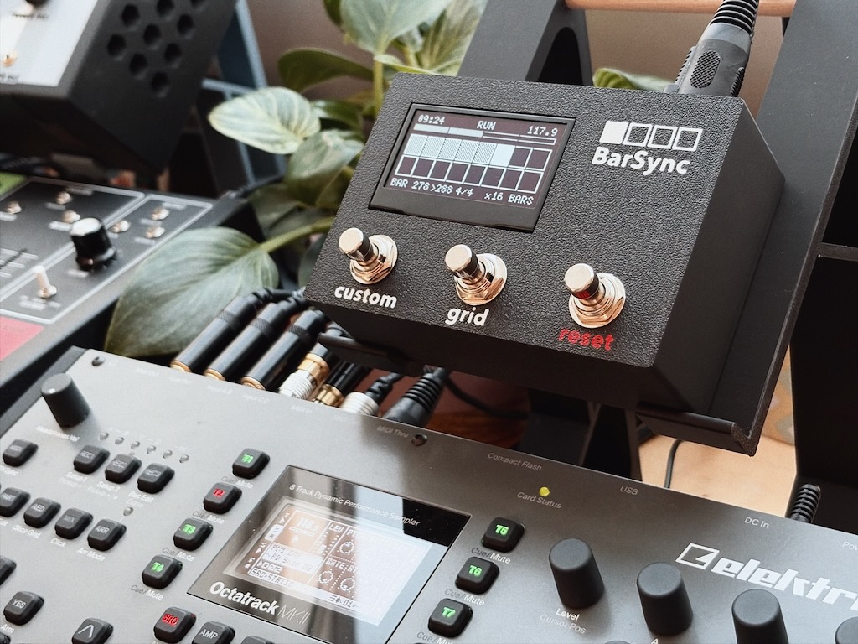
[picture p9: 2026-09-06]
images/barsync_pic1.jpeg

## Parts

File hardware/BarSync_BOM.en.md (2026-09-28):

# Bill of Materials — BarSync

*[Deutsche Version](BarSync_BOM.md)*

Based on the parts list extracted directly from `BarSync.kicad_pcb` and
`BarSync.net` — the actual current state (every reference, every value,
every footprint, and every net connection individually verified). Parts
with identical properties are grouped into a single row; the **Reichelt**
column gives the matching Reichelt order number (use it as the search
term in the shop). A ready-made shopping list is at the end of this file.

---

## Components Part 1 (on the PCB)

| Ref. | Component | Value | Qty | Footprint | Reichelt | Note |
|---|---|---|---|---|---|---|
| U1 | 6N139 | Optocoupler | 1 | DIP-8, **socketed** | `6N 139` | MIDI-IN |
| U2 | SN7406N | Hex inverter, open collector | 1 | DIP-14, **socketed** | `SN 7406N TEX` | MIDI-THRU driver, 2 gates in series |
| D1 | 1N4148 | Switching diode | 1 | DO-35, horizontal | `1N 4148` | MIDI-IN protection diode, antiparallel to U1 — **mind the polarity** |
| R1, R3, R4 | Resistor | 220 Ω | 3 | Axial 0207, horizontal | `METALL 220` | R1 = MIDI-IN series resistor · R3 = pull-up, optocoupler output → **+3V3** (not +5V — feeds ESP32 GPIO15 directly!) · R4 = MIDI-THRU current loop |
| R2 | Resistor | 4.7 kΩ | 1 | Axial 0207, horizontal | `METALL 4,70K` | Vb bias resistor (6N139) |
| C1, C2 | Capacitor | 100 nF, X7R | 2 | Radial, 5 mm pitch | `X7R-5 100N` | Decoupling capacitors U1 / U2 |
| J1, J3, J4, J5 | Pin header | 2-pin, 2.54 mm | 4 | Vertical | `SL 1X36G 2,54` ¹ | J1 = MIDI-IN · J3 = Custom · J4 = Grid · J5 = Reset |
| J2 | Pin header | 3-pin, 2.54 mm | 1 | Vertical | `SL 1X36G 2,54` ¹ | MIDI-THRU |
| J6 | Pin header | 7-pin, 2.54 mm | 1 | Vertical | `SL 1X36G 2,54` ¹ | Display |
| A1 | ESP32 DevKit (WROOM-32, DOIT, 30 pins) | — | 1 | DOIT_ESP32_DEVKIT_30Pins | — ² | Soldered directly — no socket needed, the socket in the footprint's 3D model is cosmetic only |
| — | IC socket | DIP-8 | 1 | — | `GS 8P` | for U1 |
| — | IC socket | DIP-14 | 1 | — | `GS 14P` | for U2 |
| — | Mounting hole | M2, 2.2 mm | 4 | MountingHole | — | Mechanical only, not a component |

¹ All pin headers are snapped off **one** 36-pin strip (18 pins needed).
² Not available at Reichelt in the matching format — the ESP32-DevKitC sold there has 38 pins and does **not** fit the 30-pin footprint. The board built and tested is the **ELEGOO ESP-WROOM-32** (30 pins) — Amazon: [link](https://www.amazon.de/dp/B0D8T5XD3P).

**Total: 4 resistors, 2 capacitors, 1 diode, 2 ICs (socketed), 6 pin headers, 1 ESP32, 4 mounting holes.**

---

## Components Part 2 (connected to the board via cables)

| Component | Qty | Source | Note |
|---|---|---|---|
| OLED display SSD1309, 2.42", 128×64, SPI, 7-pin connector | 1 | Amazon: [Hailege 2.42" SSD1309](https://www.amazon.de/dp/B0CJY4WP8C) ³ | Via 7-pin Dupont cable to J6 |
| DIN-5 panel-mount socket (flange with 2 screw holes) | 2 | Amazon: [Link](https://www.amazon.de/dp/B0D22R6Q9R) | MIDI-IN + MIDI-THRU, matching the enclosure cutout |
| Stomp footswitch, SPST, momentary (panel mount, with lock nut) | 3 | Amazon: [Link](https://www.amazon.de/dp/B09KN9HJ7M) | Custom, Grid, Reset |
| Dupont cable female-female, 2-pin | 4 | Reichelt `DEBO KABELSET19` ⁴ | J1 (MIDI-IN) + J3/J4/J5 (buttons) |
| Dupont cable female-female, 3-pin | 1 | Reichelt `DEBO KABELSET19` ⁴ | J2 (MIDI-THRU) |
| Dupont cable female-female, 7-pin | 1 | Reichelt `DEBO KABELSET19` ⁴ | J6 (display) |

³ The Hailege module (7-pin SPI) is the one built and tested. The 2.42" OLED at Reichelt (`DEBO OLED 2.42`), by contrast, has a 20-pin connector and does not plug directly into J6.
⁴ All Dupont connections come from **one** ribbon jumper cable `DEBO KABELSET19` (40 wires, female-female, 15 cm): peel off as many wires as each connection needs (18 wires in total). Each wire has its own single-pin housing — keep the wire order identical at both ends; bundle with tape if desired.

---

## Components Part 3 (Enclosure Fastening Hardware)

| Component | Value | Qty | Note |
|---|---|---|---|
| Threaded insert, Ruthex | M3 | 4 | Enclosure top |
| Socket head screw | M3×12 | 4 | Enclosure, into threaded inserts |
| Phillips screw | M1.7×4 | 4 | Display |
| Socket head screw | M2×10 | 8 | PCB (4) + MIDI sockets (4) |
| Nut | M2 | 4 | MIDI sockets |
| Washer | M2 | 4 | MIDI sockets |

---

## Reichelt Shopping List

**Ready-made cart:** [https://www.reichelt.de/my/2391791](https://www.reichelt.de/my/2391791) — all parts with the correct quantities,
add them to your own Reichelt cart in one click. Alternatively search the
order numbers individually, or use the list as CSV:
[`BarSync_Reichelt.csv`](BarSync_Reichelt.csv).

| Reichelt order no. | Description | Qty |
|---|---|---|
| `6N 139` | Optocoupler, DIP-8 | 1 |
| `SN 7406N TEX` | Hex inverter, open collector, DIL-14 | 1 |
| `1N 4148` | Switching diode, DO-35 | 1 |
| `METALL 220` | Resistor 220 Ω, metal film, 0207 | 3 |
| `METALL 4,70K` | Resistor 4.7 kΩ, metal film, 0207 | 1 |
| `X7R-5 100N` | Ceramic capacitor 100 nF, X7R, 5 mm pitch | 2 |
| `GS 8P` | IC socket, 8-pin | 1 |
| `GS 14P` | IC socket, 14-pin | 1 |
| `SL 1X36G 2,54` | Pin header strip, 36-pin, straight | 1 |
| `DEBO KABELSET19` | Ribbon jumper cable, 40 wires, female-female, 15 cm (wires separable) | 1 |

Not at Reichelt (source separately, electronics sources in Parts 1 and 2): ESP32 DevKit DOIT 30-pin, OLED
SSD1309 2.42" SPI (7-pin), 2× DIN-5 panel-mount socket, 3× stomp footswitch,
Ruthex M3 threaded inserts and M1.7/M2/M3 screws, nuts and washers.

---

## Sourcing Notes

- **Resistors:** metal film, 0207 size (0.6 W, 1 %) — fits the 1/4 W
  footprint; the extra power rating does no harm
- **Capacitors (C1/C2):** 100 nF, X7R (not Y5V/Z5U — more stable over
  temperature/voltage), THT, 5.0 mm pitch
- **Pin headers (J1–J6):** all 2.54 mm pitch, straight/vertical
- Order numbers checked on Sep 28, 2026 (all in stock); availability may change

---

*Created for BarSync hardware rev. 1.2 — matches `BarSync.kicad_pcb`/`.net` as of
Sep 17, 2026 (D1 antiparallel to U1). Changes vs. rev. 1.0: fixed R3 pull-up
(+5V → +3V3, protects ESP32 GPIO15), added C1/C2 as decoupling capacitors, tied
unused 7406 gate inputs to GND. See `CHANGELOG.en.md`. BOM grouped and Reichelt
order numbers added on Sep 28, 2026.*

---

*[Deutsche Version](BarSync_BOM.md)*

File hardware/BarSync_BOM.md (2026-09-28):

# Bill of Materials — BarSync

*[English version](BarSync_BOM.en.md)*

Basierend auf der direkt aus `BarSync.kicad_pcb` und `BarSync.net` ausgewerteten,
tatsächlich aktuellen Bauteilliste (jede Referenz, jeder Wert, jeder Footprint
und jede Netzverbindung einzeln verifiziert). Bauteile mit identischen
Eigenschaften sind in einer Zeile zusammengefasst; die Spalte **Reichelt**
nennt die passende Reichelt-Artikelnummer (Suchbegriff im Shop). Eine
fertige Einkaufsliste steht am Ende dieser Datei.

---

## Bauteile Part 1 (auf der Platine)

| Ref. | Bauteil | Wert | Menge | Footprint | Reichelt | Hinweis |
|---|---|---|---|---|---|---|
| U1 | 6N139 | Optokoppler | 1 | DIP-8, **gesockelt** | `6N 139` | MIDI-IN |
| U2 | SN7406N | Hex-Inverter, Open-Kollektor | 1 | DIP-14, **gesockelt** | `SN 7406N TEX` | MIDI-THRU-Treiber, 2 Gatter in Reihe |
| D1 | 1N4148 | Schaltdiode | 1 | DO-35, liegend | `1N 4148` | MIDI-IN-Schutzdiode, antiparallel zu U1 — **Polarität beachten** |
| R1, R3, R4 | Widerstand | 220 Ω | 3 | Axial 0207, liegend | `METALL 220` | R1 = MIDI-IN-Vorwiderstand · R3 = Pull-up Opto-Ausgang → **+3V3** (nicht +5V — geht direkt auf ESP32 GPIO15!) · R4 = MIDI-THRU-Stromschleife |
| R2 | Widerstand | 4,7 kΩ | 1 | Axial 0207, liegend | `METALL 4,70K` | Vb-Ableitwiderstand (6N139) |
| C1, C2 | Kondensator | 100 nF, X7R | 2 | Radial, RM 5 | `X7R-5 100N` | Abblockkondensatoren U1 / U2 |
| J1, J3, J4, J5 | Stiftleiste | 2-polig, 2,54 mm | 4 | Vertikal | `SL 1X36G 2,54` ¹ | J1 = MIDI-IN · J3 = Custom · J4 = Grid · J5 = Reset |
| J2 | Stiftleiste | 3-polig, 2,54 mm | 1 | Vertikal | `SL 1X36G 2,54` ¹ | MIDI-THRU |
| J6 | Stiftleiste | 7-polig, 2,54 mm | 1 | Vertikal | `SL 1X36G 2,54` ¹ | Display |
| A1 | ESP32 DevKit (WROOM-32, DOIT, 30 Pins) | — | 1 | DOIT_ESP32_DEVKIT_30Pins | — ² | Wird direkt eingelötet — kein Sockel nötig, der Sockel im 3D-Modell des Footprints ist rein kosmetisch |
| — | IC-Sockel | DIP-8 | 1 | — | `GS 8P` | für U1 |
| — | IC-Sockel | DIP-14 | 1 | — | `GS 14P` | für U2 |
| — | Befestigungsloch | M2, 2,2 mm | 4 | MountingHole | — | Nur mechanisch, kein Bauteil |

¹ Alle Stiftleisten werden von **einer** 36-poligen Leiste abgebrochen (benötigt: 18 Pins).
² Bei Reichelt nicht im passenden Format erhältlich — das dort geführte ESP32-DevKitC hat 38 Pins und passt **nicht** auf den 30-Pin-Footprint. Verbaut und getestet ist das **ELEGOO ESP-WROOM-32** (30 Pins) — Amazon: [Link](https://www.amazon.de/dp/B0D8T5XD3P).

**Insgesamt 4 Widerstände, 2 Kondensatoren, 1 Diode, 2 ICs (gesockelt), 6 Stiftleisten, 1 ESP32, 4 Befestigungslöcher.**

---

## Bauteile Part 2 (per Kabel mit der Platine verbunden)

| Bauteil | Menge | Bezugsquelle | Hinweis |
|---|---|---|---|
| OLED-Display SSD1309, 2,42", 128×64, SPI, 7-poliger Anschluss | 1 | Amazon: [Hailege 2,42" SSD1309](https://www.amazon.de/dp/B0CJY4WP8C) ³ | Über 7-poliges Dupont-Kabel an J6 |
| DIN-5-Buchse (Einbau, Flansch mit 2 Schraublöchern) | 2 | Amazon: [Link](https://www.amazon.de/dp/B0D22R6Q9R) | MIDI-IN + MIDI-THRU, passend zum Gehäuseausschnitt |
| Stomp-Fußschalter, SPST, tastend (Einbau, mit Kontermutter) | 3 | Amazon: [Link](https://www.amazon.de/dp/B09KN9HJ7M) | Custom, Grid, Reset |
| Dupont-Kabel Buchse-Buchse, 2-polig | 4 | Reichelt `DEBO KABELSET19` ⁴ | J1 (MIDI-IN) + J3/J4/J5 (Taster) |
| Dupont-Kabel Buchse-Buchse, 3-polig | 1 | Reichelt `DEBO KABELSET19` ⁴ | J2 (MIDI-THRU) |
| Dupont-Kabel Buchse-Buchse, 7-polig | 1 | Reichelt `DEBO KABELSET19` ⁴ | J6 (Display) |

³ Verbaut und getestet ist das Hailege-Modul (7-polig SPI). Das 2,42"-OLED bei Reichelt (`DEBO OLED 2.42`) hat dagegen einen 20-poligen Anschluss und passt nicht direkt an J6.
⁴ Alle Dupont-Verbindungen aus **einem** Flachband-Steckbrückenkabel `DEBO KABELSET19` (40 Adern, Buchse-Buchse, 15 cm): Adern je nach Polzahl abtrennen (18 Adern benötigt). Jede Ader hat einen einpoligen Stecker — Adern an beiden Enden in derselben Reihenfolge aufstecken; bei Bedarf mit Tape bündeln.

---

## Bauteile Part 3 (Gehäuse-Befestigungsmaterial)

| Bauteil | Wert | Menge | Hinweis |
|---|---|---|---|
| Gewindeeinsatz Ruthex | M3 | 4 | Gehäuseoberteil |
| Inbusschraube | M3×12 | 4 | Gehäuse, in die Gewindeeinsätze |
| Kreuzschlitzschraube | M1,7×4 | 4 | Display |
| Inbusschraube | M2×10 | 8 | Platine (4) + MIDI-Buchsen (4) |
| Mutter | M2 | 4 | MIDI-Buchsen |
| Unterlegscheibe | M2 | 4 | MIDI-Buchsen |

---

## Einkaufsliste Reichelt

**Fertiger Warenkorb:** [https://www.reichelt.de/my/2391791](https://www.reichelt.de/my/2391791) — alle Positionen mit den richtigen
Mengen, per Klick in den eigenen Reichelt-Warenkorb übernehmen. Alternativ
die Artikelnummern einzeln im Shop suchen, oder die Liste als CSV:
[`BarSync_Reichelt.csv`](BarSync_Reichelt.csv).

| Reichelt-Artikelnr. | Bezeichnung | Menge |
|---|---|---|
| `6N 139` | Optokoppler, DIP-8 | 1 |
| `SN 7406N TEX` | Hex-Inverter Open-Kollektor, DIL-14 | 1 |
| `1N 4148` | Schaltdiode, DO-35 | 1 |
| `METALL 220` | Widerstand 220 Ω, Metallschicht, 0207 | 3 |
| `METALL 4,70K` | Widerstand 4,7 kΩ, Metallschicht, 0207 | 1 |
| `X7R-5 100N` | Keramikkondensator 100 nF, X7R, RM 5 | 2 |
| `GS 8P` | IC-Sockel, 8-polig | 1 |
| `GS 14P` | IC-Sockel, 14-polig | 1 |
| `SL 1X36G 2,54` | Stiftleiste 36-polig, gerade | 1 |
| `DEBO KABELSET19` | Steckbrückenkabel 40 Adern, Buchse-Buchse, 15 cm (Adern abtrennbar) | 1 |

Nicht bei Reichelt (separat besorgen, Bezugsquellen für Elektronik siehe Part 1 und 2): ESP32 DevKit DOIT 30-Pin, OLED
SSD1309 2,42" SPI (7-polig), 2× DIN-5-Einbaubuchse, 3× Stomp-Fußschalter,
Ruthex-Gewindeeinsätze M3 sowie Schrauben/Muttern/Scheiben M1,7/M2/M3.

---

## Bestellhinweise

- **Widerstände:** Metallschicht, Bauform 0207 (0,6 W, 1 %) — passt in den
  1/4-W-Footprint; mehr Belastbarkeit schadet nicht
- **Kondensatoren (C1/C2):** 100 nF, X7R (nicht Y5V/Z5U — stabiler über
  Temperatur/Spannung), bedrahtet, RM 5,0 mm
- **Stiftleisten (J1–J6):** alle im 2,54-mm-Raster, gerade/vertikal
- Artikelnummern geprüft am 28.09.2026 (alle ab Lager); Verfügbarkeit kann sich ändern

---

*Erstellt für BarSync Hardware-Rev. 1.2 — Stand entspricht `BarSync.kicad_pcb`/`.net`
vom 17.09.2026 (D1 antiparallel zu U1). Änderungen gegenüber Rev. 1.0: R3-Pull-up
korrigiert (+5V → +3V3, schützt ESP32 GPIO15), C1/C2 als Abblockkondensatoren
ergänzt, ungenutzte 7406-Gate-Eingänge auf GND gelegt. Siehe `CHANGELOG.md`.
BOM am 28.09.2026 zusammengefasst und um Reichelt-Artikelnummern ergänzt.*

---

*[English version](BarSync_BOM.en.md)*

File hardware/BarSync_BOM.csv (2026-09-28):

Ref | Bauteil | Wert | Menge | Footprint/Typ | Reichelt | Hinweis
U1 | 6N139 | Optokoppler | 1 | DIP-8 gesockelt | 6N 139 | MIDI-IN
U2 | SN7406N | Hex-Inverter Open-Kollektor | 1 | DIP-14 gesockelt | SN 7406N TEX | MIDI-THRU-Treiber 2 Gatter in Reihe
D1 | 1N4148 | Schaltdiode | 1 | DO-35 liegend | 1N 4148 | MIDI-IN Schutzdiode antiparallel zu U1 - Polaritaet beachten
R1, R3, R4 | Widerstand | 220R | 3 | Axial 0207 liegend | METALL 220 | R1 MIDI-IN Vorwiderstand / R3 Pull-up nach +3V3 (nicht +5V) / R4 MIDI-THRU Stromschleife
R2 | Widerstand | 4k7 | 1 | Axial 0207 liegend | METALL 4,70K | Vb-Ableitwiderstand
C1, C2 | Kondensator | 100nF X7R | 2 | Radial RM5 | X7R-5 100N | Abblockkondensatoren U1 / U2
J1, J3, J4, J5 | Stiftleiste | 2-polig 2.54mm | 4 | Vertikal | SL 1X36G 2,54 | J1 MIDI-IN / J3 Custom / J4 Grid / J5 Reset - alle Stiftleisten aus einer 36er-Leiste
J2 | Stiftleiste | 3-polig 2.54mm | 1 | Vertikal | SL 1X36G 2,54 | MIDI-THRU
J6 | Stiftleiste | 7-polig 2.54mm | 1 | Vertikal | SL 1X36G 2,54 | Display
A1 | ESP32 DevKit (WROOM-32 DOIT 30 Pins) | - | 1 | DOIT_ESP32_DEVKIT_30Pins | - | Direkt eingeloetet - nicht bei Reichelt (DevKitC 38 Pins passt nicht) - Amazon https://www.amazon.de/dp/B0D8T5XD3P (ELEGOO ESP-WROOM-32)
- | IC-Sockel | DIP-8 | 1 | - | GS 8P | Fuer U1
- | IC-Sockel | DIP-14 | 1 | - | GS 14P | Fuer U2
- | Befestigungsloch | M2 2.2mm | 4 | MountingHole | - | Nur mechanisch
- | OLED-Display | SSD1309 2.42 Zoll 128x64 SPI 7-polig | 1 | - | - | Via 7-pol Kabel an J6 - Amazon https://www.amazon.de/dp/B0CJY4WP8C (Hailege)
- | DIN-5-Buchse Einbau | Flansch 2 Schraubloecher | 2 | - | - | MIDI-IN + MIDI-THRU - Amazon https://www.amazon.de/dp/B0D22R6Q9R
- | Stomp-Fussschalter SPST tastend | mit Kontermutter | 3 | - | - | Custom/Grid/Reset - Amazon https://www.amazon.de/dp/B09KN9HJ7M
- | Dupont-Kabel BB | 2-polig | 4 | - | (aus DEBO KABELSET19) | J1 + J3 + J4 + J5
- | Dupont-Kabel BB | 3-polig | 1 | - | (aus DEBO KABELSET19) | J2
- | Dupont-Kabel BB | 7-polig | 1 | - | (aus DEBO KABELSET19) | J6
- | Gewindeeinsatz Ruthex | M3 | 4 | - | - | Gehaeuseoberteil
- | Inbusschraube | M3x12 | 4 | - | - | Gehaeuse in Gewindeeinsaetze
- | Kreuzschlitzschraube | M1.7x4 | 4 | - | - | Display
- | Inbusschraube | M2x10 | 8 | - | - | Platine (4) + MIDI-Buchsen (4)
- | Mutter | M2 | 4 | - | - | MIDI-Buchsen
- | Unterlegscheibe | M2 | 4 | - | - | MIDI-Buchsen
- | Steckbrueckenkabel BB (Flachband) | 40 Adern 15cm | 1 | - | DEBO KABELSET19 | Quelle fuer alle Dupont-Verbindungen - Adern je nach Polzahl abtrennen

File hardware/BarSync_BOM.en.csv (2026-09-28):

Ref | Component | Value | Qty | Footprint/Type | Reichelt | Note
U1 | 6N139 | Optocoupler | 1 | DIP-8 socketed | 6N 139 | MIDI-IN
U2 | SN7406N | Hex inverter open collector | 1 | DIP-14 socketed | SN 7406N TEX | MIDI-THRU driver 2 gates in series
D1 | 1N4148 | Switching diode | 1 | DO-35 horizontal | 1N 4148 | MIDI-IN protection diode antiparallel to U1 - mind polarity
R1, R3, R4 | Resistor | 220R | 3 | Axial 0207 horizontal | METALL 220 | R1 MIDI-IN series resistor / R3 pull-up to +3V3 (not +5V) / R4 MIDI-THRU current loop
R2 | Resistor | 4k7 | 1 | Axial 0207 horizontal | METALL 4,70K | Vb bias resistor
C1, C2 | Capacitor | 100nF X7R | 2 | Radial 5mm pitch | X7R-5 100N | Decoupling capacitors U1 / U2
J1, J3, J4, J5 | Pin header | 2-pin 2.54mm | 4 | Vertical | SL 1X36G 2,54 | J1 MIDI-IN / J3 Custom / J4 Grid / J5 Reset - all headers from one 36-pin strip
J2 | Pin header | 3-pin 2.54mm | 1 | Vertical | SL 1X36G 2,54 | MIDI-THRU
J6 | Pin header | 7-pin 2.54mm | 1 | Vertical | SL 1X36G 2,54 | Display
A1 | ESP32 DevKit (WROOM-32 DOIT 30 pins) | - | 1 | DOIT_ESP32_DEVKIT_30Pins | - | Soldered directly - not at Reichelt (38-pin DevKitC does not fit) - Amazon https://www.amazon.de/dp/B0D8T5XD3P (ELEGOO ESP-WROOM-32)
- | IC socket | DIP-8 | 1 | - | GS 8P | For U1
- | IC socket | DIP-14 | 1 | - | GS 14P | For U2
- | Mounting hole | M2 2.2mm | 4 | MountingHole | - | Mechanical only
- | OLED display | SSD1309 2.42 inch 128x64 SPI 7-pin | 1 | - | - | Via 7-pin cable to J6 - Amazon https://www.amazon.de/dp/B0CJY4WP8C (Hailege)
- | DIN-5 panel-mount socket | Flange 2 screw holes | 2 | - | - | MIDI-IN + MIDI-THRU - Amazon https://www.amazon.de/dp/B0D22R6Q9R
- | Stomp footswitch SPST momentary | with lock nut | 3 | - | - | Custom/Grid/Reset - Amazon https://www.amazon.de/dp/B09KN9HJ7M
- | Dupont cable FF | 2-pin | 4 | - | (from DEBO KABELSET19) | J1 + J3 + J4 + J5
- | Dupont cable FF | 3-pin | 1 | - | (from DEBO KABELSET19) | J2
- | Dupont cable FF | 7-pin | 1 | - | (from DEBO KABELSET19) | J6
- | Threaded insert Ruthex | M3 | 4 | - | - | Enclosure top
- | Socket head screw | M3x12 | 4 | - | - | Enclosure into threaded inserts
- | Phillips screw | M1.7x4 | 4 | - | - | Display
- | Socket head screw | M2x10 | 8 | - | - | PCB (4) + MIDI sockets (4)
- | Nut | M2 | 4 | - | - | MIDI sockets
- | Washer | M2 | 4 | - | - | MIDI sockets
- | Ribbon jumper cable FF | 40 wires 15cm | 1 | - | DEBO KABELSET19 | Source for all Dupont connections - peel off wires as needed

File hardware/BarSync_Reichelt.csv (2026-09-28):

Reichelt-Artikelnr. | Bezeichnung | Menge | Verwendung | Link
6N 139 | Optokoppler, DIP-8 | 1 | U1 | https://www.reichelt.de/de/de/shop/produkt/optok-darl_2_5kv_18v_60ma_dip8-2860
SN 7406N TEX | Hex-Inverter Open-Kollektor, DIL-14 | 1 | U2 | https://www.reichelt.de/de/de/shop/produkt/inverter_hex_4_75_5_25_v_dil-14-216958
1N 4148 | Schaltdiode, DO-35 | 1 | D1 | https://www.reichelt.de/de/de/shop/produkt/schalt-diode_100_v_150_ma_do-35-1730
METALL 220 | Widerstand 220 Ohm, Metallschicht, 0207 | 3 | R1, R3, R4 | https://www.reichelt.de/de/de/shop/produkt/widerstand_metallschicht_220_ohm_0207_0_6_w_1_-11627
METALL 4,70K | Widerstand 4,7 kOhm, Metallschicht, 0207 | 1 | R2 | https://www.reichelt.de/de/de/shop/produkt/widerstand_metallschicht_4_70_kohm_0207_0_6_w_1_-11784
X7R-5 100N | Keramikkondensator 100 nF, X7R, RM 5 | 2 | C1, C2 | https://www.reichelt.de/de/de/shop/produkt/vielschicht-kerko_100_nf_50_100_v_x7r_10_rm_5_0-22865
GS 8P | IC-Sockel, 8-polig | 1 | U1 | https://www.reichelt.de/de/de/shop/produkt/ic-sockel_8-polig_superflach_gedreht-8231
GS 14P | IC-Sockel, 14-polig | 1 | U2 | https://www.reichelt.de/de/de/shop/produkt/ic-sockel_14-polig_superflach_gedreht_vergold_-8207
SL 1X36G 2,54 | Stiftleiste 36-polig, gerade, RM 2,54 | 1 | J1-J6 (18 Pins) | https://www.reichelt.de/de/de/shop/produkt/-19504
DEBO KABELSET19 | Steckbrückenkabel 40 Adern, Buchse-Buchse, 15 cm | 1 | Kabel J1-J6 (18 Adern) | https://www.reichelt.de/de/de/shop/produkt/-282699

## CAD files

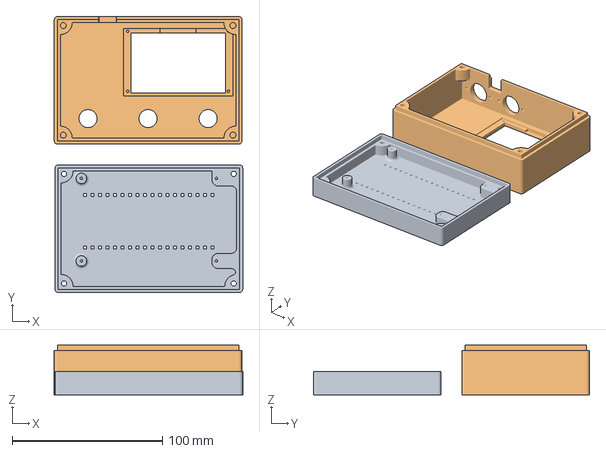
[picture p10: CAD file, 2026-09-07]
enclosure/BarSync_Inserts_Inverted_V1.2.3mf
125.5 x 183.8 x 33.0 mm

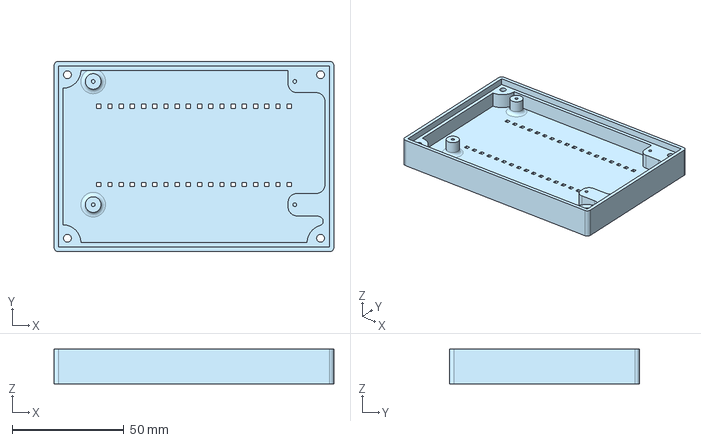
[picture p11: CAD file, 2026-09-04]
enclosure/BarSync_Inserts_V1.2_bottom.step
125.0 x 85.0 x 15.5 mm

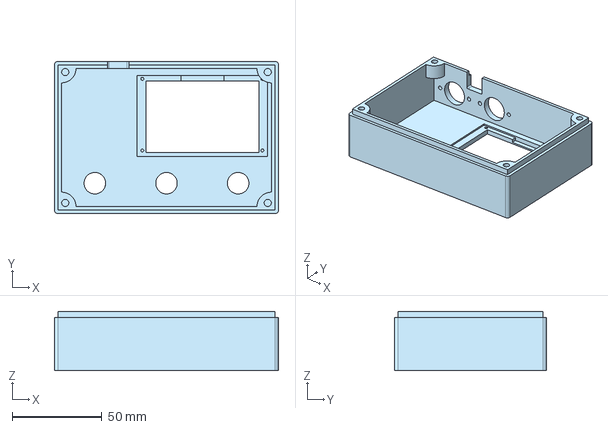
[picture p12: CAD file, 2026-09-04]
enclosure/BarSync_Inserts_V1.2_top.step
125.0 x 85.0 x 33.0 mm

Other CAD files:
enclosure/BarSync_Inserts_V1.2.3mf

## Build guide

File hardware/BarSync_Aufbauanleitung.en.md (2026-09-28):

# Assembly Guide — BarSync

*[Deutsche Version](BarSync_Aufbauanleitung.md)*

Recommended build order, from simplest to most demanding.
Parts list and references match the verified `BarSync_BOM_en.md`.

---

## 1. Preparation

- Open the [`schematic`](kicad/BarSync/BarSync_schematic.pdf)
- Check off all components against `BarSync_BOM_en.md`/`.csv` before you start
- **All four resistor positions (R1–R4) are populated** — no position is left empty

## 2. Solder the Small Parts First

Order: start with the flattest/most robust components, then the more delicate ones.

1. **Resistors R1, R2, R3, R4** (polarity doesn't matter, no orientation to worry about)
2. **Capacitors C1, C2** (100nF, ceramic/X7R — also non-polarized, can be soldered either way round)
3. **Diode D1** — mind the polarity! The cathode band on the diode must point toward the corresponding marking on the board
4. **DIP sockets** for U1 (8-pin) and U2 (14-pin) — the notch/dot on the socket marks pin 1; align it with the marking on the board

## 3. Solder the Headers

5. **J1** (2-pin, MIDI-IN), **J2** (3-pin, MIDI-THRU), **J3/J4/J5** (2-pin each, buttons), **J6** (7-pin, display)
- Solder all of them straight and vertical — it's best to tack down one pin first, check the alignment, and only then solder the rest

## 4. Solder the ESP32 onto the Board

6. Place the ESP32 in its designated spot and solder it in
   > **Note:** Contrary to how the KiCad footprint (`DOIT_ESP32_DEVKIT_30Pins`) looks, the ESP32 is soldered **directly onto the board, with no socket/female headers in between**. The footprint's 3D model suggests a socket, but that's purely cosmetic. Only the peripheral headers (J1–J6) get pin headers — not the ESP32 itself.

## 5. Insert the ICs

7. **6N139** into the DIP-8 socket (U1) — mind the notch
8. **SN7406N** into the DIP-14 socket (U2) — mind the notch

## 6. Fit the Electronics into the Enclosure

Required hardware (see `BarSync_BOM_en.md`/`.csv`):

- 4× Ruthex threaded insert, M3
- 4× socket-head screw M3×12
- 4× Phillips screw M1.7×4
- 8× socket-head screw M2×10
- 4× nut M2
- 4× washer M2

9. **Fit the PCB:** Position the PCB in the bottom half of the enclosure and screw it down with 4× M2×10 socket-head screws into the designated mount
10. **Display:** Mount the display with 4× M1.7×4 Phillips screws
11. **MIDI jacks:** Insert the MIDI jacks (mind the IN/THRU arrangement), fasten with 4× M2×10 socket-head screws, and secure from the inside with 4× M2 nuts and 4× M2 washers
12. **Mount the buttons:** Insert the 3× buttons (Custom, Grid, Reset) into their designated openings and secure with the lock nuts
13. **Set the threaded inserts:** Press/melt the 4× Ruthex threaded inserts (M3) into the corresponding mounts in the top half of the enclosure (set the soldering iron to roughly the material's forming temperature — e.g. 220°C for PLA)

## 7. Prepare and Connect the Cables

!!!IMPORTANT: make sure the polarity/pinout matches the [`schematic`](kicad/BarSync/BarSync_schematic.pdf)!!!

14. Plug the Dupont cables into the corresponding headers:
    - J1 (2-pin) → MIDI-IN socket (pin 4 + pin 5 of the DIN-5 socket)
    - J2 (3-pin) → MIDI-THRU socket (pin 2 + pin 4 + pin 5 of the DIN-5 socket)
    - J3/J4/J5 → respective button
    - J6 (7-pin) → display

## 8. Flash the Firmware

This section is deliberately detailed — including for anyone who has never worked with the Arduino IDE before.

15. **Install the Arduino IDE** (if not already installed): download the current version from https://www.arduino.cc/en/software and install it
16. **Add ESP32 board support**:
    - Open the Arduino IDE
    - File → Preferences (Windows) or Arduino IDE → Settings (Mac)
    - In the "Additional boards manager URLs" field, enter: `https://raw.githubusercontent.com/espressif/arduino-esp32/gh-pages/package_esp32_index.json`
    - Click OK
    - Tools → Board → Boards Manager → search for "esp32" → install the **"esp32 by Espressif Systems"** package (takes a few minutes, it's fairly large)
17. **Select the board**: Tools → Board → esp32 → **ESP32 Dev Module**
18. **Install the libraries** (if not done already): Sketch → Include Library → Manage Libraries → search for and install **"MIDI Library"** (FortySevenEffects) and **"U8g2"** (olikraus)
19. Connect the board to the computer via USB cable
20. **If no port shows up under Tools → Port**: the USB driver for the board's chip is probably missing — see the "Install the USB driver" box right below
21. **Select the port**: Tools → Port → choose the matching port (Windows: e.g. `COM3`; Mac: e.g. `/dev/cu.usbserial-...` or `/dev/cu.SLAB_USBtoUART`)
22. Open `barsync.ino` (located in the `firmware/barsync/` folder in the repo)
23. **Upload**: click the arrow button in the top-left of the Arduino IDE. If the upload fails with a timeout: set Tools → Upload Speed to `115200` and try again

> ### Install the USB driver (only needed if no port shows up)
>
> Most ESP32 boards use a **CP2102** USB chip for the USB connection. For the computer to recognize the board as a serial port, it needs a driver for that chip — this isn't included by default in Windows or macOS.
>
> **Windows:**
> 1. Open https://www.silabs.com/software-and-tools/usb-to-uart-bridge-vcp-drivers in your browser
> 2. Scroll to "Downloads", download the **"CP210x Windows Drivers"** (ZIP file)
> 3. Extract the ZIP file (right-click → Extract All)
> 4. In the extracted folder, run the included `.exe` installer if there is one. If there isn't: open the Windows Device Manager (right-click the Start menu → Device Manager) → look for the board under "Other devices" or "Ports (COM & LPT)" (often shown with a warning icon) → right-click it → "Update driver" → "Browse my computer for drivers" → select the extracted folder
> 5. Unplug and replug the board's USB cable
> 6. A COM port should now appear under Tools → Port in the Arduino IDE (e.g. `COM3`)
>
> **Mac:**
> 1. Open https://www.silabs.com/software-and-tools/usb-to-uart-bridge-vcp-drivers in your browser
> 2. Scroll to "Downloads", download the **"CP210x VCP Mac OSX Driver"** (ZIP containing a `.pkg` installer)
> 3. Unzip it, double-click the `.pkg` file and follow the installation steps
> 4. macOS blocks newly installed system extensions by default — right after installation you'll usually see a "System Extension Blocked" notice. Then: open System Settings → Privacy & Security, scroll to the bottom where a notice about the blocked extension from "Silicon Laboratories" appears → click "Allow"
> 5. Restart the Mac (macOS requires this after installing a kernel extension)
> 6. Reconnect the board via USB
> 7. An entry like `/dev/cu.SLAB_USBtoUART` or `/dev/cu.usbserial-...` should now appear under Tools → Port in the Arduino IDE
>
> If your board instead has a **CH340/CH341** chip (usually printed directly on the small IC next to the USB connector), you'll need the matching **WCH CH340 driver** instead of the CP210x one — same idea, different download source (manufacturer: WCH).

## 9. First Functional Test — Before Closing the Enclosure

24. On startup, the display should show the boot screen ("BarSync")
25. Connect a MIDI source, start the clock → the display should switch to "RUN"
26. Test all three buttons individually (trigger the Custom button — currently: SET 1.1 —, change Grid, trigger Reset)
27. Only once everything works: screw the top and bottom enclosure halves together with 4× M3×12 socket-head screws

---

## Known Pitfalls

| Problem | Solution |
|---|---|
| Display stays dark | Check SPI wiring at J6 (pin order), check contrast in the setup menu |
| No MIDI signal detected | Check optocoupler orientation (U1) and D1 polarity |
| Buttons don't respond or respond incorrectly | Check the mapping: J3=Custom(GPIO32), J4=Grid(GPIO33), J5=Reset(GPIO25) |

---

*For BarSync hardware rev. 1.2 — component references verified against `BarSync.kicad_pcb`/`.net`.
See also `pinplan_en.md` for the full pin reference and `CHANGELOG_en.md` for the change history.*

---

*[Deutsche Version](BarSync_Aufbauanleitung.md)*

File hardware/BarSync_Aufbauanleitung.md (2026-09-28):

# Aufbauanleitung — BarSync

*[English version](BarSync_Aufbauanleitung.en.md)*

Empfohlene Reihenfolge für den Zusammenbau, vom Einfachsten zum Anspruchsvollsten.
Bauteilliste und Referenzen entsprechen der verifizierten `BarSync_BOM.md`.

---

## 1. Vorbereitung

- [`Schaltplan`](kicad/BarSync/BarSync_schematic.pdf) öffnen
- Alle Bauteile gegen die `BarSync_BOM.md`/`.csv` durchzählen, bevor du anfängst
- **Alle vier Widerstands-Positionen (R1–R4) werden bestückt** — keine Position bleibt leer

## 2. Kleinteile zuerst löten

Reihenfolge: erst die flachsten/robustesten Bauteile, dann die empfindlicheren.

1. **Widerstände R1, R2, R3, R4** (Polarität egal, keine Ausrichtung zu beachten)
2. **Kondensatoren C1, C2** (100nF, Keramik/X7R — ebenfalls keine Polarität, in beide Richtungen einlötbar)
3. **Diode D1** — Polarität beachten! Kathoden-Ring auf der Diode muss zur entsprechenden Markierung auf der Platine zeigen
4. **DIP-Sockel** für U1 (8-polig) und U2 (14-polig) — Kerbe/Punkt am Sockel zeigt Pin 1 an, mit der Markierung auf der Platine ausrichten

## 3. Stiftleisten löten

5. **J1** (2-polig, MIDI-IN), **J2** (3-polig, MIDI-THRU), **J3/J4/J5** (je 2-polig, Taster), **J6** (7-polig, Display)
- Alle vertikal, gerade einlöten — am besten erst einen Pin anlöten, Ausrichtung prüfen, dann erst die restlichen fixieren

## 4. ESP32 auf Platine verlöten

6. ESP32 auf dem vorgesehenen Platz einsetzen und verlöten
   > **Hinweis:** Der ESP32 wird — entgegen dem Erscheinungsbild des KiCad-Footprints (`DOIT_ESP32_DEVKIT_30Pins`) — **direkt und ohne Zwischenstecker/Sockelleiste** auf die Platine gelötet. Der Footprint suggeriert durch sein 3D-Modell einen Sockel, dieser ist aber rein kosmetisch. Nur die Peripherie-Header (J1–J6) erhalten Stiftleisten, nicht der ESP32 selbst.

## 5. ICs einsetzen

7. **6N139** in den DIP-8-Sockel (U1) — Kerbe beachten
8. **SN7406N** in den DIP-14-Sockel (U2) — Kerbe beachten

## 6. Einbau der Elektronik ins Gehäuse

Benötigtes Befestigungsmaterial (siehe `BarSync_BOM.md`/`.csv`):

- 4× Gewindeeinsatz Ruthex, M3
- 4× Inbusschraube M3×12
- 4× Kreuzschlitzschraube M1,7×4
- 8× Inbusschraube M2×10
- 4× Mutter M2
- 4× Unterlegscheibe M2

9. **Platine einsetzen:** Platine im Gehäuseunterteil positionieren und mit den 4× M2×10-Inbusschrauben in der dafür vorgesehenen Aufnahme verschrauben
10. **Display:** Display mit den 4× M1,7×4-Kreuzschlitzschrauben befestigen
11. **Midi-Buchsen:** Midibuchsen einsetzen (Anordnung IN und THRU beachten), mit den 4× M2×10-Inbusschrauben verschrauben und mit 4× M2-Muttern und 4× M2-Unterlegscheiben auf der Innenseite kontern
12. **Taster montieren:** Die 3× Taster (Custom, Grid, Reset) in die dafür vorgesehenen Öffnungen einsetzen und mit den Kontermuttern sichern
13. **Gewindeeinsätze setzen:** Die 4× Ruthex-Gewindeeinsätze (M3) in die entsprechenden Aufnahmen des Gehäuseoberteils einpressen/einschmelzen (die Temperatur des Lötkolbens etwa auf die Drucktemperatur des Materials - bei PLA z.B. 220°C)

## 7. Kabel vorbereiten und anschließen

!!!WICHTIG: auf die korrekte Polarität/Pinbelegung gemäß [`Schaltplan`](kicad/BarSync/BarSync_schematic.pdf) achten!!!

14. Dupont-Kabel an die entsprechenden Header stecken:
    - J1 (2-pol.) → MIDI-IN-Buchse (Pin 4 + Pin 5 der DIN-5-Buchse)
    - J2 (3-pol.) → MIDI-THRU-Buchse (Pin 2 + Pin 4 + Pin 5 der DIN-5-Buchse)
    - J3/J4/J5 → jeweiliger Taster
    - J6 (7-pol.) → Display

## 8. Firmware flashen

Dieser Abschnitt ist bewusst ausführlich gehalten — auch für alle, die noch nie mit der Arduino-IDE gearbeitet haben.

15. **Arduino IDE installieren** (falls noch nicht vorhanden): aktuelle Version von https://www.arduino.cc/en/software herunterladen und installieren
16. **ESP32-Boardunterstützung hinzufügen**:
    - Arduino IDE öffnen
    - Datei → Voreinstellungen (Windows) bzw. Arduino IDE → Einstellungen (Mac)
    - Feld "Zusätzliche Boardverwalter-URLs" → eintragen: `https://raw.githubusercontent.com/espressif/arduino-esp32/gh-pages/package_esp32_index.json`
    - Mit OK bestätigen
    - Tools → Board → Boardverwalter (Boards Manager) → nach "esp32" suchen → Paket **"esp32 by Espressif Systems"** installieren (dauert ein paar Minuten, ist recht groß)
17. **Board auswählen**: Tools → Board → esp32 → **ESP32 Dev Module**
18. **Bibliotheken installieren** (falls noch nicht geschehen): Sketch → Bibliothek einbinden → Bibliotheken verwalten → **"MIDI Library"** (FortySevenEffects) und **"U8g2"** (olikraus) suchen und jeweils installieren
19. Board per USB-Kabel mit dem Rechner verbinden
20. **Falls unter Tools → Port kein Port auftaucht**: fehlt vermutlich der USB-Treiber für den Chip auf dem Board — siehe Kasten "USB-Treiber installieren" direkt unten
21. **Port auswählen**: Tools → Port → passenden Port wählen (Windows: z. B. `COM3`; Mac: z. B. `/dev/cu.usbserial-...` oder `/dev/cu.SLAB_USBtoUART`)
22. `barsync.ino` öffnen (liegt im Ordner `firmware/barsync/` im Repo)
23. **Hochladen**: Pfeil-Button oben links in der Arduino-IDE klicken. Bricht der Upload mit Timeout ab: Tools → Upload Speed auf `115200` stellen und erneut versuchen

> ### USB-Treiber installieren (nur nötig, falls kein Port erscheint)
>
> Die meisten ESP32-Boards verwenden einen **CP2102**-USB-Chip für die USB-Verbindung. Damit der Rechner das Board als seriellen Port erkennt, braucht es dafür einen Treiber — der ist nicht automatisch in Windows oder macOS enthalten.
>
> **Windows:**
> 1. https://www.silabs.com/software-and-tools/usb-to-uart-bridge-vcp-drivers im Browser öffnen
> 2. Zu "Downloads" scrollen, die **"CP210x Windows Drivers"** (ZIP-Datei) herunterladen
> 3. ZIP-Datei entpacken (Rechtsklick → Alle extrahieren)
> 4. Im entpackten Ordner die enthaltene `.exe`-Installationsdatei ausführen, falls vorhanden. Ist keine dabei: Windows-Gerätemanager öffnen (Rechtsklick auf Start-Menü → Geräte-Manager) → unter "Andere Geräte" oder "Anschlüsse (COM & LPT)" das Board suchen (oft mit Warnsymbol) → rechtsklicken → "Treiber aktualisieren" → "Auf dem Computer nach Treibersoftware suchen" → den entpackten Ordner auswählen
> 5. Board kurz aus- und wieder einstecken (USB-Kabel abziehen und neu verbinden)
> 6. In der Arduino-IDE unter Tools → Port sollte jetzt ein COM-Port erscheinen (z. B. `COM3`)
>
> **Mac:**
> 1. https://www.silabs.com/software-and-tools/usb-to-uart-bridge-vcp-drivers im Browser öffnen
> 2. Zu "Downloads" scrollen, die **"CP210x VCP Mac OSX Driver"** herunterladen (ZIP mit `.pkg`-Installer drin)
> 3. ZIP entpacken, die `.pkg`-Datei doppelklicken und den Installationsschritten folgen
> 4. macOS blockiert neu installierte Systemerweiterungen standardmäßig — meist erscheint direkt nach der Installation ein Hinweis "Systemerweiterung blockiert". Dann: Systemeinstellungen → Datenschutz & Sicherheit öffnen, ganz unten auf der Seite erscheint ein Hinweis auf die blockierte Erweiterung von "Silicon Laboratories" → auf "Zulassen" klicken
> 5. Mac neu starten (macOS verlangt das nach der Installation einer Kernel-Erweiterung)
> 6. Board per USB wieder anschließen
> 7. In der Arduino-IDE unter Tools → Port sollte jetzt ein Eintrag wie `/dev/cu.SLAB_USBtoUART` oder `/dev/cu.usbserial-...` erscheinen
>
> Falls dein Board stattdessen einen **CH340/CH341**-Chip hat (steht meist direkt auf dem kleinen IC neben dem USB-Anschluss aufgedruckt), brauchst du statt des CP210x-Treibers den passenden **WCH-CH340-Treiber** — gleiches Prinzip, andere Downloadquelle (Hersteller: WCH).

## 9. Erster Funktionstest — vor dem schließen des Gehäuses

24. Display sollte bei Start den Boot-Screen zeigen ("BarSync")
25. MIDI-Quelle anschließen, Clock starten → Anzeige sollte auf "RUN" wechseln
26. Alle drei Taster einzeln durchtesten (Custom-Taster auslösen — aktuell: SET 1.1 —, Grid wechseln, Reset auslösen)
27. Erst wenn alles funktioniert: Gehäuse oberteil und Unterteil mit 4× M3×12-Inbusschrauben verschrauben

---

## Bekannte Stolperfallen

| Problem | Lösung |
|---|---|
| Display bleibt dunkel | SPI-Verkabelung an J6 prüfen (Pin-Reihenfolge), Kontrast im Setup-Menü prüfen |
| Kein MIDI-Signal erkannt | Optokoppler-Orientierung (U1) und D1-Polarität prüfen |
| Taster reagieren nicht/falsch | Zuordnung prüfen: J3=Custom(GPIO32), J4=Grid(GPIO33), J5=Reset(GPIO25) |

---

*Für BarSync Hardware-Rev. 1.2 — Bauteilreferenzen verifiziert gegen `BarSync.kicad_pcb`/`.net`.
Siehe auch `pinplan.md` für die vollständige Pin-Referenz und `CHANGELOG.md` für die Änderungshistorie.*

---

*[English version](BarSync_Aufbauanleitung_en.md)*

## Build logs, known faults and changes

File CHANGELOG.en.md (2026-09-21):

# Changelog — BarSync

*[Deutsche Version](https://github.com/barna81/BarSync/blob/main/CHANGELOG.md)*

## Firmware v1.3.2 (2026-09-22)

**Introduced a browser-based firmware flasher.** Firmware can now be
flashed straight from the browser (Chrome/Edge) — no Arduino IDE, no
manual driver install: https://barna81.github.io/BarSync/flash/. A
GitHub Actions workflow builds a ready-to-flash binary automatically
on every version tag (compiled with pinned toolchain versions: esp32
core 3.3.12, MIDI Library 5.0.2, U8g2 2.36.19) and publishes it both
as a GitHub Release asset and same-origin next to the flash page
itself. The manual Arduino IDE route remains available (see Chapter 8
of the Assembly Guide) and is now listed as the alternative in the
README.

This release contains no functional firmware changes — `FW_VERSION`
was bumped solely to confirm the complete release workflow (tag →
automatic build → release → flash page) end-to-end with a real
version number.

Affects: `.github/workflows/build-firmware.yml`, `docs/flash/*`,
`README.md`/`.de.md`.

---

## Hardware Rev. 1.2 (2026-09-17)

**D1 rewired from a series diode to an antiparallel protection diode.**
D1 (1N4148) previously sat in series in the MIDI input path (documented
as a "series-resistor diode"); it's now wired in reverse-parallel
across the input LED of optocoupler U1 (6N139) — D1's anode ties to the
net at U1 pin 3 (opto-LED cathode), D1's cathode ties to the net at U1
pin 2 (opto-LED anode, via R1/220Ω). In normal operation D1 now blocks
completely and only conducts on a reversed or negative voltage spike at
the MIDI input, clamping it to protect the opto-LED from exceeding its
reverse breakdown voltage — without the extra forward voltage drop the
previous series arrangement added to the signal path.

D1 was also physically relocated on the PCB (new footprint position),
and several GND traces around U1 had their width adjusted to route the
new wiring cleanly; gerber files were re-exported accordingly.

Affects: `hardware/kicad/BarSync/BarSync.kicad_sch`,
`BarSync.kicad_pcb`, `BarSync.net`, `hardware/kicad/BarSync/gerbers/*`.
The separate `BarSync_Thru4.kicad_sch` (4-way MIDI-thru variant, still
in progress) is unaffected by this change and is not part of this
release. D1's BOM description ("MIDI-IN series-resistor diode") was
outdated after this change and has now been updated.

---

## Firmware v1.3.1 (2026-09-16)

**Extended playtime and bar counter limits.** The playtime display now
runs up to 999:59 (previously 99:59) before wrapping back to 00:00.
The bar count is now hard-capped at 9999 (matching the existing
marker/End Bar ceiling) — reaching bar 10000 wraps the count back to
bar 1, beat 1, resetting the elapsed play time too.

**SCROLL mode: a clearer sense of motion.** With no markers placed,
the SCROLL grid previously gave almost no visual indication that bars
were actually advancing. Blocks of however many bars the current grid
view spans (e.g. at x4: bars 1-4, 5-8, 9-12, ...) now visibly
alternate between plain and a dithered pattern — a continuous stripe
pattern that scrolls left along with the bars. Markers sit inside a
small, clean border, with only the surrounding area dithered. The
"last bar of this block" number now blinks on the beat (instead of
staying on screen permanently) and also appears over a marker and on
the current bar position itself.

**Grid counter and BPM detection now keep running seamlessly while
Operation Setup is open.** Previously, the count froze completely for
as long as the menu was open (on any screen), then jumped abruptly to
the current value once you left.

**New info screens in Operation Setup.** The first time you switch to
SCROLL, or the first time you open SET MARKERS, per menu session, a
brief one-time note appears (SCROLL: capped at a max. of 16 bars; SET
MARKERS: markers only show in grid views x1-x16, or continuously in
SCROLL mode).

**Bug fixes:**

- An aborted Custom+Reset or Custom+Grid button press (e.g. released
before the 1-second threshold was reached) could, depending on
release order, accidentally trigger Reset 1, SET 1.1, or a grid
change. The affected button combos now only trigger once their own
hint sweep was actually visible.
- SET 1.1 used to fall back to a full reset while stopped (clock not
running) — that fallback is now gone entirely; SET 1.1 does nothing
while stopped.
- The reset confirmation showed "RESET 2" permanently while stopped
(and more generally stayed on screen indefinitely instead of
clearing after a moment) — now correctly shows "RESET 1" and clears
itself as expected.

Affects: `firmware/barsync.ino`. No hardware changes in this version.

---

## Firmware v1.3.0 (2026-09-11)

**New: Marker Editor.** You can now place your own markers directly on
the bar grid (four symbols to choose from) — handy for anything that
needs a fixed reference to the bar count:

- Mark arrangement changes (break, drop, build), so you always know
what's coming next.
- Flag the start of each phrase, so the band can follow the arrangement
live without memorizing it.
- Cue points for planned lighting/FX changes, synced exactly to the bar.

Reached via `OPERATION SETUP > SET MARKERS`.

**New: two grid display modes.** `CYCLE` loops the grid repeatedly
through the same window of bars (x1 to x128) — you see where you stand
within the current cycle. `SCROLL` instead runs continuously forward,
always showing the current bar plus what's coming up next, including
any markers you've placed scrolling in from the right. Switchable via `OPERATION SETUP > GRID MODE`.

**New: End Bar.** Defines a bar at which the count should loop back,
stop, or simply carry on - either at a fixed bar number, or
automatically at your last placed marker. Configurable via `OPERATION SETUP > END BAR` / `END BAR ACT`.

Affects: `firmware/barsync.ino`. No hardware changes in this version.

---

## Firmware v1.2.2 (2026-09-06)

**MIDI Analyzer replaced with MIDI Monitor.** The previous jitter
analysis (deviation graph, peak-hold scaling) has been removed
entirely — the benefit no longer justified the complexity, and the
associated render-time diagnostic (`Rmax`) was only ever a temporary
debug aid anyway. The screen (still reached by holding the custom
button for 1s) now shows:

- **Note/CC/Program Change/Pitch Bend log**: the last 6 received
messages, newest on top, older ones pushed down and dropped after
6 entries. Plain FIFO buffer, no per-channel dedup.
- **MIDI clock graph**: one spike per detected beat, independent of
Start/Stop (so it still shows an incoming-but-stopped signal). Now
always exactly 8 beats wide, so the sample rate automatically scales
with tempo. The downbeat (1.1, time-signature aware) is marked with
a double-width spike. The "MIDI CLK" label flashes inverted on the
beat, and shows a blinking "NO CLOCK" if no clock byte has arrived
for 5s.
- **RUN/STOP trace**: level trace on the same timebase as the clock
graph.
- **BPM readout** top right, one decimal place.
- The reset button clears the Note/CC log on this screen instead of
triggering the normal Reset 1/2 function.

**Divisor/Grid menu: visible label finally switched to "Grid".** After
the button silkscreen and all documents were already renamed to "Grid"
in the last update, the corresponding setup menu item itself
(`SWITCHES > DIVISOR` / `DIVISOR SELECT`) still internally said
"Divisor". Now consistently `GRID` / `GRID SELECT`. Internal firmware
identifiers (`divisorIndex`, `PIN_BTN_DIVISOR`, `SCR_DIVISOR`, etc.)
are unchanged, same as with the button rename.

**Grid view: 32-bar group separators for x16/x32/x64/x128**, each with
its own separator thickness so the overall height stays exactly
identical across every divisor view (35px, previously a fixed 32px).
Can now be turned off via `DISPLAY > GRID LINES` (Yes/default,
No = original layout with no grouping at all).

**x128 view: remaining-bars indicator on the right edge** (adopted
from the Eurorack variant) — one tick per row (= 8 bars) not yet
played through, visibly counting down from 16 to 0, current row
blinks on the beat.

**New contrast steps and defaults:**

- Contrast steps now `25/50/100/150/200/255` (previously
`50/100/150/200/255`), default 50 (previously 255).
- Grid Select (divisor selection) now starts with x4–x128 enabled
(x1/x2 disabled) instead of all — matches the Eurorack variant's
factory default.

**Boot screen: BarSync logo added**, to the left of the "**BARSYNC**"
text — the four tiles fill up in step with the loading blink cadence,
fully filled after at most 4 blink cycles.

Affects: `firmware/barsync.ino`. No hardware changes in this version.

---

## Hardware Rev. 1.2 (2026-09-05)

**Button net name in the schematic/netlist renamed from "Divisor
Switch" to "Grid Switch"** — a pure identifier change in the KiCad
project (schematic and netlist), no electrical or pin change. This
completes the renaming that previously only covered the enclosure
print and documentation (see entry below), now also carried through
into the KiCad project.

**PCB silkscreen updated:** the corresponding button's label on the
board changed from "DIVISOR" to "GRID", matching the enclosure print.

Affects: `hardware/kicad/BarSync/BarSync.kicad_sch`, `BarSync.kicad_pcb`, `BarSync.net`/`BarSync_Netlist.txt`. Internal
firmware identifiers (`divisor`, `divisorIndex`, `PIN_BTN_DIVISOR`,
etc.) remain unchanged.

## Firmware v1.2.0 (2026-09-02)

**Bugfix: BarSync stayed frozen at its pre-sleep state after waking
from standby, even with MIDI clock already running - only a manual
Stop+Run on the sequencer got it moving again.** Root cause: `isRunning` is only ever set by an explicit Start/Continue message. If
the sequencer was already running when it woke us up (no fresh Start/
Continue, since from its side playback never stopped), Clock ticks did
arrive, but those alone never set `isRunning` - BarSync was waiting for
a message that was never going to come. Fix: if the wake reason wasn't
a button (so, presumably, MIDI activity), every temporary grid/time
value is now cleared and BarSync starts fresh at 1.1 right away,
regardless of whether an explicit Start message follows. If one does
arrive anyway, it just harmlessly resets everything again; if no real
clock follows at all, the existing clock-loss watchdog
(`CLOCK_LOST_TIMEOUT_MS`) catches that on its own within a few seconds.

**Bugfix: short button presses were sometimes swallowed entirely.** The old debounce required a new level to stay stable for at least
50ms before it counted as a change at all - a press-and-release that
both happened inside that window was never recognized as "stable" and
simply vanished, rather than just being delayed. Switched to
edge-triggered debounce instead: the edge is accepted immediately,
followed by a 50ms blackout window against contact bounce. Affects
all three buttons equally, since they all go through the same `updateButton()` function.

**SET 1.1 (QUANTIZED mode) now rounds to the nearest beat instead of
always rounding down to the last one that passed.** If the press is
closer to the upcoming beat than the current one, it now waits briefly
(at most 12 ticks, i.e. at most half a beat) and commits exactly there,
instead of always snapping backward to the beat that already passed.

**Menu refinement: reorganized the custom role and reset settings.**

- `Switches > Custom > FUNCTION` now only has two roles: `TIMESIG` and
`SET 1.1` (**new default**) — `RESET 1`/`RESET 2` are removed
entirely as custom-button roles (the physical reset button keeps its
two stages unchanged).
- With `FUNCTION = TIMESIG` set, a new **`TIMESIGS >`** entry appears
below it — a checkbox list of which of the five time signatures the
custom button cycles through (default: all). The fixed time
signature value on page 1 (`SETUP > TIMESIG`) is unaffected and
still rotates through all five.
- With `FUNCTION = SET 1.1` set, a new **`MODE`** (QUANTIZED/INSTANT)
appears directly below it instead — the setting that used to live
under `Switches > Reset` has moved here, since it only ever affects
SET 1.1.
- `Switches > Custom Switch` (formerly "Custom Role") and
`Switches > Reset Switch` (formerly "Reset") renamed.
- `Switches > Reset Switch` now has **`RESET 1`** and **`RESET 2`** (both Yes/No, default Yes) — independently configurable per stage
whether it also resets the elapsed play time. The bar counter/grid
always resets regardless (no separate switch for that anymore - the
`BARCOUNTER` option introduced in the meantime is removed again).
SET 1.1 is unaffected by this and always resets everything.
- **Menu visually unified:** every settings page now uses the same
grid (item spacing, explanation position, explanation font size) -
previously this differed from page to page (e.g. 8px here, 12px
there). The explanation text also now consistently runs in the
smaller font.

**Bugfix: BarSync only responded to the second RUN/Start command from
the sequencer after standby (light sleep) - and the original fix for
this caused an even worse follow-on bug.**

Root cause of the original bug: the GPIO level wakeup on the MIDI RX
line only guarantees that the CPU wakes up - not that the UART
peripheral cleanly receives the very byte that triggered the wakeup
(the clock supply needs a brief moment to stabilize after light
sleep).

The original fix (clearing the UART buffer after waking + calling `MIDI.begin()` again) didn't fix the problem, though - it replaced it
with a worse one: if a MIDI clock was already running when it woke up
(sequencer already playing), clearing the buffer also discarded the
real Start command and any clock ticks that had already arrived - `isRunning` stayed false, counters/time/grid stayed completely frozen
at their pre-sleep state until a fresh, independent Stop+Start pair
came through. `MIDI.begin()` carries the same risk indirectly, since
the library re-initializes the transport internally, which can also
reset the underlying UART and clear its buffer.

**Final fix:** both (buffer-clearing and the `MIDI.begin()` call)
removed again. All that's left is a brief stabilization pause after
waking - which is enough, since MIDI real-time messages (Clock/Start/
Stop/Continue) are single bytes that, unlike channel messages, don't
expect "running status" and therefore can't throw the parser off step,
even if that one byte happens to arrive corrupted. The beat
extrapolation anchor (`lastTickAnchorMicros`) is also still reset on
waking, so no stale pre-sleep timestamp can briefly cause a wrong
display.

**Reset logic reworked**, inspired by concepts from the Eurorack
version, but with its own distinct result after several iterations:

- Only **two reset stages** on the physical button (Reset 1/Reset 2)
instead of three - stage 3 is gone. Short press = Reset 1, hold past
1s = Reset 2 (press mechanics unchanged).
- **Reset 1** still waits for the **end of the current bar** as
before, **Reset 2** for the **end of the divisor cycle** - both
operate within whatever beat pattern is currently active, without
changing it themselves.
- **New: `SET 1.1`** - a standalone, instant-acting function, only
assignable to the custom button via `Switches > Custom > FUNCTION` (not reachable via the physical reset button). Immediately
establishes a new "1.1" anchor, spinning up a brand new beat
pattern within which Reset 1 and 2 then keep operating. Configurable
via `Switches > Reset > MODE`:
  * **QUANTIZED** (default): rounds the new anchor down to the
nearest beat boundary already existing in the current grid - the
existing beat pattern (since MIDI Start or a previous SET 1.1)
stays in phase, only our own count is nudged back in line with
the sequencer. Example: the display sits at bar 1, beat 2, tick 1
    + SET 1.1 pulls the new 1.1 to exactly where the 1.2 just was.
  * **INSTANT**: uses the exact raw tick of the trigger as-is,
spinning up a brand new beat pattern independent of the previous
grid.
- New setting `Switches > Reset > PLAYTIME` (Yes/No, default Yes):
whether a reset (1, 2, or SET 1.1) also resets the elapsed play
time - independent of which of the three functions it is.
- **Flash feedback adopted from the Eurorack:** after every reset
action, "RESET 1"/"RESET 2"/"SET 1.1" now blinks exactly 2x on the
beat (instead of time-based), in addition to the brief instant flash
animation.

**The custom button is now freely assignable** (`Switches > Custom`),
instead of permanently cycling the time signature:

- New setting `Switches > Custom > FUNCTION` with four possible roles:
`TIMESIG` (default, previous behavior), `RESET 1`, `RESET 2`,
`SET 1.1`. The two reset roles directly trigger the correspondingly
named, already-existing reset stage - with a single short press,
without the otherwise-required differently-timed hold on the reset
button itself; they wait for the bar/cycle end just like the
physical button normally would. `SET 1.1`, by contrast, always acts
instantly (see above).
- The time signature has been decoupled from the button cycle for
this and now lives **fixed as its own menu item on page 1** (`SETUP > TIMESIG`), directly switchable between the five existing
time signatures (default: 4/4). The previous screen for showing/
hiding individual time signatures for button cycling
(`Switches > Timesig`) is gone without replacement - it no longer
made sense without a dedicated time-signature button; all five time
signatures are now always reachable.
- Holding the custom button for 1s (toggle MIDI analyzer), the nudge
combo (Custom+Divisor), and the MidiWar easter egg (Custom+Reset)
remain unchanged and work independently of the chosen role.

**Settings menu fundamentally reworked**, adopted from the multi-level
menu redesign of the Eurorack firmware (there as of 2026-08-30) -
adapted for the desktop version:

- Menu is now two-tiered (`SETUP > SWITCHES/DISPLAY/STANDBY/DEFAULTS > detail page`) instead of a flat 6-item list. DIVISOR and the new
RESET live under `SWITCHES` (now alongside `CUSTOM`), CONTRAST and
INVERT under `DISPLAY`.
- A brief explanation at the bottom of the screen on the detail pages
(DISPLAY, STANDBY, CUSTOM, RESET), where there's room for it on the
128×64 landscape display. Deliberately left out on DIVISOR SELECT -
with up to 8 entries there's no vertical room left for it (unlike
the Eurorack version's taller portrait display), but the checkboxes
are self-explanatory anyway.
- `DEFAULTS` now asks via its own YES/NO confirmation page, instead of
the previous "press again to confirm".
- **Not adopted:** the Eurorack version's CV Inputs category (no CV
hardware on this board) and `DISPLAY > ROTATE` (this unit is
permanently mounted in landscape, no runtime rotation needed).

**Renaming (continuing rev. 1.1):** internal firmware identifiers for
the custom button (`PIN_BTN_TIMESIG`, `btnTimeSig`, `onTimeSigButton`,
etc.) renamed to `Custom` (`PIN_BTN_CUSTOM`, `btnCustom`, `onCustomButton`), matching the custom-switch renaming already done in
the schematic. Identifiers that belong to the time-signature logic
itself (`timeSigIndex`, `TIME_SIG_*`, etc.) are unchanged, since they
are independent of which button triggers them. The time-signature
enable/disable mask (`enabledTimeSigMask` etc.) was removed entirely
along with the button reassignment above, since it no longer served a
purpose without a dedicated time-signature button.

Affects: `firmware/barsync.ino`. No hardware changes in this version.

---

## Hardware Rev. 1.1 (2026-08-25)

**Important fix:**

- **R3 (optocoupler output pull-up) corrected: +5V → +3V3.** In rev. 1.0,
this pull-up was incorrectly tied to the +5V rail. Since the same node
feeds directly into ESP32 GPIO15, GPIO15 sat near 5V continuously during
MIDI idle — outside the ESP32's specification (not 5V-tolerant, absolute
max rating roughly VDD+0.3V). Rev. 1.0 was cancelled before fabrication;
this fix is included from the start in rev. 1.1.

**Other changes:**

- **Added C1, C2** — 100nF decoupling capacitors on the Vcc/GND pins of U1
(6N139) and U2 (SN7406N) for cleaner MIDI timing.
- **Tied unused 7406 gate inputs (pins 5, 9, 11, 13) to GND** instead of
leaving them floating — avoids unnecessary switching/noise on unused TTL
inputs.

Affects: `hardware/kicad/BarSync/*`, `hardware/BarSync_BOM.md`/`.csv`, `hardware/BarSync_Aufbauanleitung.md`. The firmware (v1.0.1) is unaffected
by these changes.

---

## Hardware Rev. 1.0 / Firmware v1.0.1 (2026-08-23)

- First complete version: schematic, PCB layout, and firmware finished.
- Firmware fully in English (display text + comments).
- Settings menu, nudge mode, three-stage reset, MIDI analyzer.
- **Note:** This revision was cancelled before PCB fabrication, see rev. 1.1
above — do not build.

---

*[Deutsche Version](https://github.com/barna81/BarSync/blob/main/CHANGELOG.md)*

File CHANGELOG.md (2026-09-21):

# Changelog — BarSync

*[English version](https://github.com/barna81/BarSync/blob/main/CHANGELOG.en.md)*

## Firmware v1.3.2 (22.09.2026)

**Browser-basierter Firmware-Flasher eingeführt.** Firmware kann jetzt
direkt im Browser (Chrome/Edge) geflasht werden, ganz ohne Arduino IDE
und ohne manuelle Treiber-Installation:
https://barna81.github.io/BarSync/flash/. Ein GitHub-Actions-Workflow
baut bei jedem Versions-Tag automatisch eine fertige, geflashte Binary
(kompiliert mit fest gepinnten Toolchain-Versionen: esp32-Core 3.3.12,
MIDI Library 5.0.2, U8g2 2.36.19) und veröffentlicht sie sowohl als
GitHub-Release-Anhang als auch same-origin neben der Flash-Seite
selbst. Die manuelle Route über die Arduino IDE bleibt weiterhin
verfügbar (siehe Kapitel 8 der Aufbauanleitung) und ist jetzt in der
README entsprechend als Alternative aufgeführt.

Diese Version enthält keine funktionalen Änderungen an der Firmware
selbst — `FW_VERSION` wurde ausschließlich angehoben, um den
kompletten Release-Workflow (Tag → automatischer Build → Release →
Flash-Seite) einmal end-to-end mit einer echten Versionsnummer zu
bestätigen.

Betrifft: `.github/workflows/build-firmware.yml`, `docs/flash/*`,
`README.md`/`.de.md`.

---

## Hardware Rev. 1.2 (17.09.2026)

**D1 von Serien- auf Antiparallel-Schutzdiode umverdrahtet.** D1 (1N4148)
lag bisher in Serie im MIDI-Eingangspfad (bislang als "Vorwiderstand-
Diode" geführt); jetzt liegt sie gegenphasig parallel zum Eingangs-LED
des Optokopplers U1 (6N139) — Anode von D1 auf dem Netz von U1 Pin 3
(Kathode des Opto-LEDs), Kathode von D1 auf dem Netz von U1 Pin 2
(Anode des Opto-LEDs, über R1/220Ω). D1 sperrt dadurch im Normalbetrieb
vollständig und greift nur bei einer verpolten oder negativen
Spannungsspitze am MIDI-Eingang, um das Opto-LED vor Überschreiten
seiner Sperrspannung zu schützen — ohne den zusätzlichen
Vorwärts-Spannungsabfall im Signalpfad, den die bisherige
Serienschaltung verursacht hat.

Zusätzlich wurde D1 auf dem PCB physisch versetzt (neue Footprint-
Position) und mehrere GND-Leiterbahnen um U1 herum in der Breite
angepasst, um die neue Verdrahtung sauber zu routen; Gerber-Dateien
wurden entsprechend neu exportiert.

Betrifft: `hardware/kicad/BarSync/BarSync.kicad_sch`,
`BarSync.kicad_pcb`, `BarSync.net`, `hardware/kicad/BarSync/gerbers/*`.
Die separate `BarSync_Thru4.kicad_sch` (4-fach-MIDI-Thru-Variante, noch
in Arbeit) ist von dieser Änderung nicht betroffen und nicht Teil dieses
Releases. BOM-Beschreibung von D1 ("MIDI-IN Vorwiderstand-Diode") war
durch diese Änderung veraltet und ist jetzt angepasst.

---

## Firmware v1.3.1 (16.09.2026)

**Spielzeit- und Takt-Zähler-Grenzen erweitert.** Die Spielzeit-Anzeige
läuft jetzt bis 999:59 (vorher 99:59), bevor sie auf 00:00 zurückspringt.
Die Taktzahl ist neu hart auf 9999 begrenzt (passend zur bestehenden
Marker-/End-Bar-Obergrenze) — bei Takt 10000 springt die Zählung
automatisch zurück auf Takt 1, Beat 1, inklusive Reset der Spielzeit.

**SCROLL-Modus: deutlichere Bewegungsanzeige.** Da im SCROLL-Grid ohne
Marker bisher kaum zu erkennen war, dass die Takte tatsächlich
weiterlaufen, wechseln sich jetzt Blöcke von jeweils so vielen Takten
wie die aktuelle Grid-Ansicht (z. B. bei x4: Takt 1–4, 5–8, 9–12, ...)
sichtbar zwischen normal und einem gepunkteten Muster ab — ein
fortlaufendes Streifenmuster, das mit den Takten nach links wandert.
Marker sitzen dabei in einem kleinen, sauberen Rahmen, nur der Bereich
drumherum ist gepunktet. Die "letzter Takt dieses Päckchens"-Zahl
blinkt jetzt im Takt (statt dauerhaft angezeigt zu werden) und
erscheint auch über einem Marker sowie auf der aktuellen
Takt-Position selbst.

**Grid-Zähler und BPM-Erkennung laufen jetzt nahtlos weiter, während
Operation Setup geöffnet ist.** Vorher blieb die Zählung komplett
eingefroren, solange das Menü offen war (egal welcher Screen), und
sprang beim Verlassen abrupt auf den aktuellen Stand.

**Neue Hinweis-Screens in Operation Setup.** Beim ersten Wechsel auf
SCROLL bzw. beim ersten Aufruf von SET MARKERS pro Menü-Sitzung
erscheint einmalig ein kurzer Hinweis (SCROLL: auf max. 16 Takte
begrenzt; SET MARKERS: Marker werden nur in den Grid-Ansichten x1–x16
bzw. durchgehend im SCROLL-Modus dargestellt).

**Bugfixes:**

- Ein abgebrochener Custom+Reset- oder Custom+Grid-Tastendruck (z. B.
losgelassen, bevor die 1-Sekunden-Schwelle erreicht war) konnte je
nach Loslass-Reihenfolge versehentlich Reset 1, SET 1.1 oder einen
Grid-Wechsel auslösen. Betroffene Tastenkombinationen lösen jetzt
nur noch aus, wenn ihr eigener Hinweis-Sweep tatsächlich sichtbar war.
- SET 1.1 löste im Stopp-Zustand (Clock nicht laufend) ersatzweise
einen vollen Reset aus — das entfällt jetzt ersatzlos, SET 1.1 tut im
Stopp-Zustand nichts mehr.
- Die Reset-Bestätigung zeigte im Stopp-Zustand dauerhaft "RESET 2"
(bzw. blieb generell dauerhaft stehen, statt nach kurzer Zeit wieder
zu verschwinden) — zeigt jetzt korrekt "RESET 1" und blendet sich wie
gewohnt wieder aus.

Betrifft: `firmware/barsync.ino`. Keine Hardware-Änderungen in dieser
Version.

---

## Firmware v1.3.0 (11.09.2026)

**Neu: Marker-Editor.** Im Bar-Grid lassen sich jetzt eigene Marker setzen
(vier Symbole zur Auswahl) — praktisch für alles, was einen festen Bezug
zum Takt braucht:

- Arrangement-Wechsel markieren (Break, Drop, Aufbau), damit du immer
weißt, was als Nächstes kommt.
- Phrasenanfänge kennzeichnen, damit die Band live am Arrangement bleibt,
ohne es auswendig zu kennen.
- Cue-Punkte für geplante Licht-/FX-Wechsel, exakt auf den Takt
synchronisiert.

Erreichbar über `OPERATION SETUP > SET MARKERS`.

**Neu: zwei Darstellungsmodi fürs Grid.** `CYCLE` lässt das Grid
wiederholt durch dasselbe Taktfenster laufen (x1 bis x128) — du siehst,
wo du im aktuellen Zyklus stehst. `SCROLL` läuft stattdessen fortlaufend
weiter und zeigt immer den aktuellen Takt plus die nächsten, inklusive
bereits gesetzter Marker, die von rechts hereinlaufen. Umschaltbar über `OPERATION SETUP > GRID MODE`.

**Neu: End Bar.** Legt fest, dass die Zählung bei einem bestimmten Takt
schleift, stoppt oder einfach weiterläuft — entweder auf eine feste
Taktnummer oder automatisch auf deinen letzten gesetzten Marker.
Einstellbar über `OPERATION SETUP > END BAR` / `END BAR ACT`.

Betrifft: `firmware/barsync.ino`. Keine Hardware-Änderungen in dieser
Version.

---

## Firmware v1.2.2 (06.09.2026)

**MIDI-Analyzer durch MIDI Monitor ersetzt.** Die bisherige Jitter-Analyse
(Abweichungs-Grafik, Peak-Hold-Skalierung) ist komplett entfernt — der
Nutzen stand in keinem Verhältnis zur Komplexität, und der zugehörige
Render-Zeit-Diagnosewert (`Rmax`) war ohnehin nur ein temporäres
Debug-Hilfsmittel. Der Screen (weiterhin per 1s-Halten des Custom-Tasters
erreichbar) zeigt jetzt:

- **Note/CC/Program-Change/Pitch-Bend-Log**: die letzten 6 empfangenen
Nachrichten, neueste oben, ältere rutschen nach unten und fallen nach
6 Einträgen raus. Reiner FIFO-Puffer ohne Kanal-Deduplizierung.
- **MIDI-Clock-Graph**: ein Peak pro erkanntem Beat, unabhängig von
Start/Stop (zeigt also auch ein anliegendes, aber gestopptes Signal).
Läuft jetzt exakt 8 Beats breit, die Sample-Rate skaliert also
automatisch mit dem Tempo. Die 1.1 (Taktanfang, taktart-abhängig)
wird als doppelt breiter Strich markiert. Das "MIDI CLK"-Label
blinkt im Beat-Takt invertiert und zeigt "NO CLOCK" (blinkend), wenn
5s lang kein Clock-Byte ankam.
- **RUN/STOP-Trace**: Pegel-Verlauf auf derselben Zeitbasis wie der
Clock-Graph.
- **BPM-Anzeige** oben rechts, eine Nachkommastelle.
- Der Reset-Taster löscht in diesem Screen die Note/CC-Liste, statt
die normale Reset-1/2-Funktion auszulösen.

**Divisor/Grid-Menü: sichtbare Bezeichnung final auf "Grid" umgestellt.** Nachdem der Taster-Aufdruck und alle Dokumente bereits im letzten
Update auf "Grid" umbenannt wurden, hieß der zugehörige Menüpunkt im
Setup selbst (`SWITCHES > DIVISOR` / `DIVISOR SELECT`) intern noch
"Divisor". Jetzt konsistent `GRID` / `GRID SELECT`. Interne
Firmware-Bezeichner (`divisorIndex`, `PIN_BTN_DIVISOR`, `SCR_DIVISOR` usw.) bleiben unverändert, wie schon beim Taster-Rename.

**Grid-Ansicht: 32-Bar-Trennlinien für x16/x32/x64/x128**, jeweils mit
eigens berechneter Trennstärke, damit die Gesamthöhe für alle
Divisor-Ansichten exakt gleich bleibt (35px, vorher fix 32px). Neu
abschaltbar über `DISPLAY > GRID LINES` (Ja/Default, Nein = ursprüngliche
Darstellung ohne jede Gruppierung).

**x128-Ansicht: Resttakte-Anzeige ganz rechts** (angelehnt an die
Eurorack-Version) — ein Strich pro noch nicht durchlaufener Zeile
(= 8 Bars), zählt sichtbar von 16 auf 0 runter, aktuelle Zeile blinkt
im Beat-Takt.

**Neue Kontraststufen und Standardwerte:**

- Kontraststufen jetzt `25/50/100/150/200/255` (vorher
`50/100/150/200/255`), Default 50 (vorher 255).
- Grid Select (Divisor-Auswahl) startet jetzt mit x4–x128 aktiviert
(x1/x2 deaktiviert) statt allen — entspricht dem Werksdefault der
Eurorack-Version.

**Bootscreen: BarSync-Logo ergänzt**, links neben dem
"**BARSYNC**"-Schriftzug — die vier Kacheln füllen sich synchron zum
Blink-Takt der Ladeanzeige, sind spätestens nach 4 Blinkzyklen
vollständig gefüllt.

Betrifft: `firmware/barsync.ino`. Keine Hardware-Änderungen in dieser
Version.

---

## Hardware Rev. 1.2 (05.09.2026)

**Taster-Netzname im Schaltplan/Netzliste von "Divisor Switch" auf
"Grid Switch" umbenannt** — reine Bezeichner-Änderung im KiCad-Projekt
(Schaltplan und Netzliste), keine elektrische oder Pin-Änderung. Damit
ist die Umbenennung, die zuvor nur Gehäuse-Aufdruck und Dokumentation
betraf (siehe Eintrag unten), jetzt auch im KiCad-Projekt vollzogen.

**PCB-Silkscreen angepasst:** Beschriftung des betreffenden Tasters auf
der Platine von "DIVISOR" auf "GRID" geändert, passend zum
Gehäuse-Aufdruck.

Betrifft: `hardware/kicad/BarSync/BarSync.kicad_sch`, `BarSync.kicad_pcb`, `BarSync.net`/`BarSync_Netlist.txt`.
Firmware-interne Bezeichner (`divisor`, `divisorIndex`, `PIN_BTN_DIVISOR` etc.) bleiben weiterhin unverändert.

## Firmware v1.2.0 (02.09.2026)

**Bugfix: BarSync blieb nach dem Aufwachen aus dem Standby eingefroren
auf dem Stand vor dem Einschlafen, obwohl die MIDI-Clock bereits lief —
erst ein manuelles Stop+Run am Sequencer brachte ihn wieder zum
Laufen.** Ursache: `isRunning` wird bei uns ausschließlich durch eine
explizite Start/Continue-Nachricht gesetzt. Lief der Sequencer beim
Aufwecken bereits durch (kein neuer Start/Continue, da aus seiner Sicht
nie gestoppt wurde), kamen zwar Clock-Ticks an, aber die allein setzen `isRunning` nicht — BarSync wartete auf eine Nachricht, die nie kommen
würde. Fix: Wurde der Aufwach-Grund nicht durch einen Taster ausgelöst
(also vermutlich MIDI-Aktivität), werden jetzt alle temporären
Grid-/Zeit-Daten gelöscht und direkt bei 1.1 neu gestartet — unabhängig
davon, ob danach noch eine explizite Start-Nachricht durchkommt. Kommt
doch noch eine, setzt sie einfach harmlos erneut zurück; kommt gar kein
echter Clock hinterher, fängt die bestehende
Clock-Verlust-Erkennung (`CLOCK_LOST_TIMEOUT_MS`) das nach wenigen
Sekunden von selbst wieder ab.

**Bugfix: kurze Tastendrücke wurden manchmal komplett verschluckt.** Der alte Debounce-Mechanismus verlangte, dass ein neuer Pegel danach
mindestens 50ms durchgehend stabil blieb, bevor er überhaupt als
Wechsel galt — ein Druck+Loslassen, das komplett innerhalb dieser 50ms
passierte, wurde dadurch nie als "stabil" erkannt und verschwand
spurlos, statt nur verzögert zu werden. Umgestellt auf einen
flankenbasierten Debounce: die Flanke wird sofort akzeptiert, danach
folgt ein 50ms-Sperrfenster gegen Kontaktprellen. Betrifft alle drei
Taster gleichermaßen, da sie durch dieselbe `updateButton()`-Funktion
laufen.

**SET 1.1 (QUANTIZED-Modus) rundet jetzt auf den nächstgelegenen statt
immer auf den zuletzt vergangenen Beat.** Liegt der Tastendruck näher
am kommenden Beat als am aktuellen, wird kurz gewartet (maximal 12
Ticks, also höchstens ein halber Beat) und exakt dort committet, statt
immer rückwärts auf den letzten bereits vergangenen Beat zu runden.

**Menü-Feinschliff: Custom-Rolle und Reset-Einstellungen neu geordnet.**

- `Switches > Custom > FUNCTION` hat jetzt nur noch zwei Rollen:
`TIMESIG` und `SET 1.1` (**neuer Default**) — `RESET 1`/`RESET 2` entfallen als Custom-Taster-Rolle ersatzlos (der physische
Reset-Taster behält seine beiden Stufen unverändert).
- Ist `FUNCTION = TIMESIG` eingestellt, erscheint darunter neu
**`TIMESIGS >`** — eine Checkbox-Liste, welche der fünf Taktarten der
Custom-Taster beim Durchrotieren berücksichtigt (Default: alle). Der
feste Taktart-Wert auf Seite 1 (`SETUP > TIMESIG`) bleibt davon
unberührt und rotiert weiterhin durch alle fünf.
- Ist `FUNCTION = SET 1.1` eingestellt, erscheint darunter neu direkt
**`MODE`** (QUANTIZED/INSTANT) — die Einstellung, die vorher unter
`Switches > Reset` lag, ist jetzt hierher verschoben, da sie
ausschließlich SET 1.1 betrifft.
- `Switches > Custom Switch` (vormals "Custom Role") und
`Switches > Reset Switch` (vormals "Reset") umbenannt.
- `Switches > Reset Switch` hat jetzt **`RESET 1`** und **`RESET 2`** (beide Ja/Nein, Default Ja) — pro Stufe einzeln einstellbar, ob diese
Stufe zusätzlich die Spielzeit zurücksetzt. Der Bar-Zähler/das Grid
wird dabei immer zurückgesetzt (kein eigener Schalter mehr dafür —
die zwischenzeitlich eingeführte `BARCOUNTER`-Option entfällt wieder).
SET 1.1 bleibt davon unberührt und setzt immer alles zurück.
- **Menü optisch vereinheitlicht:** Alle Einstellungsseiten nutzen jetzt
dasselbe Raster (Punktabstand, Position der Erklärung, Schriftgröße
der Erklärungstexte) — vorher unterschied sich das von Seite zu Seite
(z. B. 8px hier, 12px dort). Die Erklärungstexte laufen jetzt
außerdem einheitlich in der kleineren Schrift.

**Bugfix: BarSync reagierte nach dem Standby (Light Sleep) erst auf den
zweiten RUN/Start-Befehl des Sequencers — und der ursprüngliche Fix
dafür hat einen noch schlimmeren Nachfolgebug verursacht.**

Ursache des ursprünglichen Bugs: Der GPIO-Level-Wakeup auf der MIDI-
RX-Leitung garantiert nur, dass die CPU aufwacht — nicht, dass die
UART-Peripherie genau das Byte, das den Wakeup auslöst, sauber
empfängt (die Taktversorgung braucht nach dem Light-Sleep einen kurzen
Moment zum Stabilisieren).

Der ursprüngliche Fix (UART-Puffer nach dem Aufwachen leeren + `MIDI.begin()` erneut aufrufen) hat das Problem aber nicht behoben,
sondern durch ein schlimmeres ersetzt: Lag beim Aufwachen bereits eine
laufende MIDI-Clock an (Sequencer läuft schon), wurden durch das Leeren
des Puffers auch das echte Start-Kommando und bereits angekommene
Clock-Ticks verworfen — `isRunning` blieb false, Zähler/Zeit/Grid
blieben komplett eingefroren auf dem Stand vor dem Einschlafen, bis ein
frisches, damit unabhängiges Stop+Start-Paar durchkam. `MIDI.begin()` birgt dasselbe Risiko indirekt, da die Bibliothek dabei intern erneut
den Transport initialisiert, was die zugrunde liegende UART ebenfalls
zurücksetzen und den Puffer leeren kann.

**Endgültiger Fix:** Beides (Puffer-Leeren und `MIDI.begin()`-Aufruf)
wieder entfernt. Es bleibt nur eine kurze Stabilisierungspause nach dem
Aufwachen — die reicht aus, da MIDI-Echtzeitnachrichten (Clock/Start/
Stop/Continue) einzelne Bytes sind, die anders als Kanalnachrichten
keinen "Running Status" erwarten und daher den Parser nicht aus dem
Tritt bringen können, selbst wenn ausgerechnet dieses eine Byte mal
korrupt ankommen sollte. Zusätzlich wird weiterhin der
Beat-Extrapolations-Anker (`lastTickAnchorMicros`) beim Aufwachen
zurückgesetzt, damit kein veralteter Zeitstempel von vor dem
Schlafengehen kurzzeitig zu einer falschen Anzeige führt.

**Reset-Logik überarbeitet**, angelehnt an Konzepte der Eurorack-Version,
aber mit eigenständigem Ergebnis nach mehreren Iterationen:

- Nur noch **zwei Reset-Stufen** am physischen Taster (Reset 1/Reset 2)
statt drei — Stufe 3 entfällt. Kurzer Druck = Reset 1, Halten über 1s
= Reset 2 (Drückmechanismus unverändert).
- **Reset 1** wartet wie eh und je auf das **Ende des aktuellen Takts**,
**Reset 2** auf das **Ende des Divisor-Zyklus** — beide arbeiten
innerhalb des gerade aktiven Beatmusters, ohne es selbst zu verändern.
- **Neu: `SET 1.1`** — eine eigenständige, sofort wirkende Funktion, nur
über `Switches > Custom > FUNCTION` auf den Custom-Taster legbar
(nicht über den physischen Reset-Taster erreichbar). Setzt sofort
einen neuen "1.1"-Anker und spannt damit ein komplett neues Beatmuster
auf, innerhalb dessen Reset 1 und 2 danach weiterarbeiten. Über
`Switches > Reset > MODE` einstellbar:
  * **QUANTIZED** (Default): rundet den neuen Anker auf den
nächstgelegenen, bereits im aktuellen Grid existierenden Beat ab —
das bestehende Beatmuster (seit MIDI-Start oder einem vorherigen
SET 1.1) bleibt phasengleich erhalten, nur unsere eigene Zählung
wird auf den Sequencer nachjustiert. Beispiel: Anzeige steht bei
Takt 1, Beat 2, Tick 1 — SET 1.1 zieht die neue 1.1 exakt dorthin,
wo eben noch die 1.2 war.
  * **INSTANT**: verwendet den exakten rohen Tick des Auslösens und
spannt damit ein komplett neues, vom bisherigen Grid unabhängiges
Beatmuster auf.
- Neue Einstellung `Switches > Reset > PLAYTIME` (Ja/Nein, Default Ja):
ob ein Reset (1, 2, oder SET 1.1) zusätzlich auch die Spielzeit
zurücksetzt — unabhängig davon, welche der drei Funktionen es ist.
- **Blitzfeedback wie beim Eurorack übernommen:** Nach jeder Reset-
Aktion blinkt "RESET 1"/"RESET 2"/"SET 1.1" jetzt exakt 2x im
Beat-Takt (statt zeitbasiert), zusätzlich zur kurzen
Sofort-Blitz-Animation.

**Custom-Taster ist jetzt frei belegbar** (`Switches > Custom`), statt
fest die Taktart zu zyklen:

- Neue Einstellung `Switches > Custom > FUNCTION` mit vier möglichen
Rollen: `TIMESIG` (Default, bisheriges Verhalten), `RESET 1`,
`RESET 2`, `SET 1.1`. Die beiden Reset-Rollen lösen direkt die
jeweils gleichnamige, bereits vorhandene Reset-Stufe aus — mit einem
einzelnen kurzen Tastendruck, ohne die sonst nötige unterschiedlich
lange Haltezeit am Reset-Taster selbst; sie warten wie der physische
Taster ganz normal auf Takt- bzw. Zyklusende. `SET 1.1` wirkt dagegen
immer sofort (siehe oben).
- Die Taktart ist dafür aus dem Taster-Zyklus herausgelöst und liegt
jetzt **fest als eigener Menüpunkt auf Seite 1** (`SETUP > TIMESIG`),
direkt zwischen den fünf vorhandenen Taktarten umschaltbar (Default:
4/4). Der bisherige Auswahl-Screen zum Ein-/Ausblenden einzelner
Taktarten für die Taster-Zyklisierung (`Switches > Timesig`) entfällt
damit ersatzlos — er ergab ohne festen Taktart-Taster keinen Sinn
mehr; alle fünf Taktarten sind jetzt immer erreichbar.
- 1s-Halten des Custom-Tasters (MIDI-Analyzer ein/aus), die
Nudge-Kombination (Custom+Divisor) sowie das MidiWar-Easter-Egg
(Custom+Reset) bleiben unverändert und funktionieren unabhängig von
der gewählten Rolle.

**Einstellungsmenü grundlegend überarbeitet**, übernommen aus dem
mehrstufigen Menü-Redesign der Eurorack-Firmware (dort Stand
30.08.2026) — angepasst auf die Desktop-Version:

- Menü jetzt zweistufig (`SETUP > SWITCHES/DISPLAY/STANDBY/DEFAULTS > Detailseite`) statt einer flachen 6-Punkte-Liste. DIVISOR und das
neue RESET liegen unter `SWITCHES` (dort jetzt neben `CUSTOM`),
CONTRAST und INVERT unter `DISPLAY`.
- Kurze Sinn-Erklärung am unteren Bildschirmrand auf den Detailseiten
(DISPLAY, STANDBY, CUSTOM, RESET), wo auf dem 128×64-Landscape-Display
Platz dafür ist. Bei DIVISOR SELECT bewusst weggelassen — bei bis zu 8
Einträgen bleibt dafür kein vertikaler Platz mehr (anders als beim
höheren Hochformat-Display der Eurorack-Version), die Checkboxen sind
aber auch so selbsterklärend.
- `DEFAULTS` fragt jetzt über eine eigene JA/NEIN-Bestätigungsseite
nach, statt wie bisher per "nochmal drücken zum Bestätigen".
- **Nicht übernommen:** die CV-Inputs-Kategorie der Eurorack-Version
(keine CV-Hardware auf diesem Board) sowie `DISPLAY > ROTATE` (dieses Gerät bleibt fest im Landscape-Format verbaut, keine
Laufzeit-Drehung nötig).

**Umbenennung (Fortführung von Rev. 1.1):** interne Firmware-Bezeichner
für den Taktart-Taster (`PIN_BTN_TIMESIG`, `btnTimeSig`, `onTimeSigButton` usw.) auf `Custom` umbenannt (`PIN_BTN_CUSTOM`, `btnCustom`, `onCustomButton`), passend zur Custom-Switch-Umbenennung im Schaltplan.
Rein funktionslogische Bezeichner der Taktart-Auswahl selbst
(`timeSigIndex`, `TIME_SIG_*` usw.) bleiben unverändert, da sie
unabhängig vom auslösenden Taster sind. Die Ein-/Ausblende-Maske für
Taktarten (`enabledTimeSigMask` u.ä.) wurde mit der Taster-Freigabe
oben komplett entfernt, da sie ohne festen Taktart-Taster keinen Zweck
mehr hatte.

Betrifft: `firmware/barsync.ino`. Keine Hardware-Änderungen in dieser
Version.

---

## Hardware Rev. 1.1 (25.08.2026)

**Wichtiger Fix:**

- **R3 (Pull-up des Optokoppler-Ausgangs) korrigiert: +5V → +3V3.** In Rev. 1.0
hing dieser Pull-up fälschlicherweise am +5V-Netz. Da derselbe Knoten direkt
auf ESP32 GPIO15 geführt ist, lag GPIO15 im MIDI-Ruhezustand dauerhaft nahe
5V an — außerhalb der Spezifikation des ESP32 (nicht 5V-tolerant, absolute
Grenzspannung ca. VDD+0,3V). Rev. 1.0 wurde vor Fertigung storniert, dieser
Fix ist von Anfang an in Rev. 1.1 enthalten.

**Weitere Änderungen:**

- **C1, C2 ergänzt** — 100nF-Abblockkondensatoren an den Vcc/GND-Pins von U1
(6N139) und U2 (SN7406N) für saubereres MIDI-Timing.
- **Ungenutzte 7406-Gate-Eingänge (Pins 5, 9, 11, 13) auf GND gelegt**, statt
offen zu bleiben — vermeidet unnötiges Schalten/Rauschen an unbenutzten
TTL-Eingängen.

Betrifft: `hardware/kicad/BarSync/*`, `hardware/BarSync_BOM.md`/`.csv`, `hardware/BarSync_Aufbauanleitung.md`. Die Firmware (v1.0.1) ist von diesen
Änderungen nicht betroffen.

---

## Hardware Rev. 1.0 / Firmware v1.0.1 (23.08.2026)

- Erste vollständige Version: Schaltplan, PCB-Layout und Firmware fertig.
- Firmware komplett auf Englisch (Display-Texte + Kommentare).
- Settings-Menü, Nudge-Modus, Drei-Stufen-Reset, MIDI-Analyzer.
- **Hinweis:** Diese Revision wurde vor der PCB-Fertigung storniert, siehe
Rev. 1.1 oben — nicht nachbauen.

---

*[English version](https://github.com/barna81/BarSync/blob/main/CHANGELOG.en.md)*

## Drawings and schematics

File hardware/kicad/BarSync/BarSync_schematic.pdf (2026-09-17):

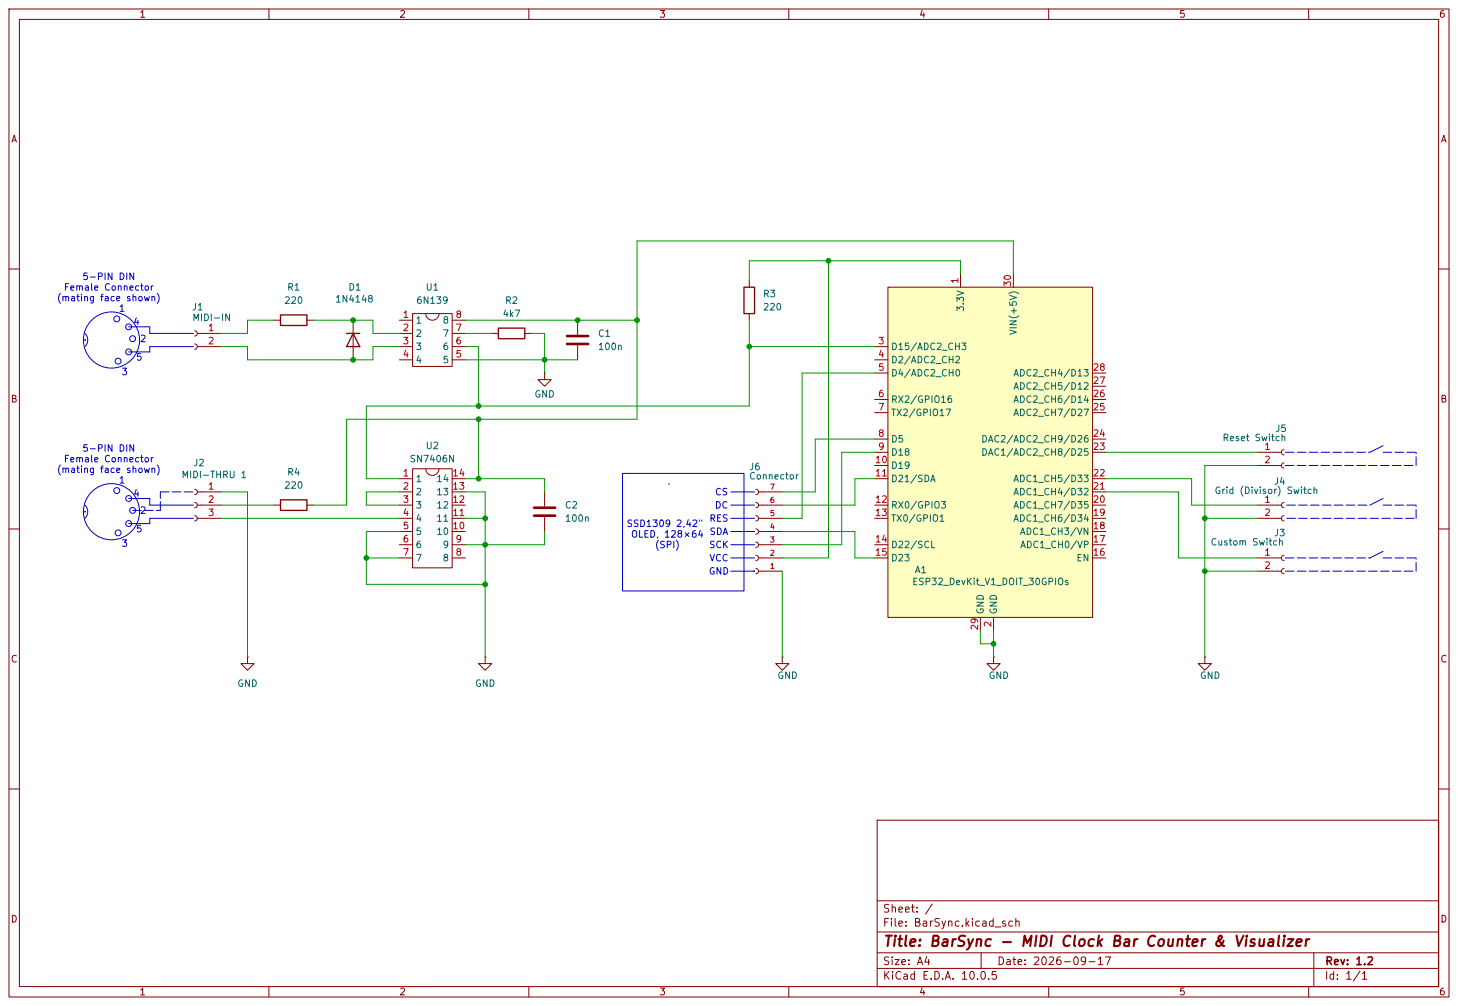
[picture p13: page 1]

5-PIN DIN
Female Connector (mating face shown) 2

Sheet: /
File: BarSync.kicad_sch
Title: BarSync - MIDI Clock Bar Counter & Visualizer

Size: A4 | Rev: 1.2
KiCad E.D.A. 10.0.5 | Id: 1/1

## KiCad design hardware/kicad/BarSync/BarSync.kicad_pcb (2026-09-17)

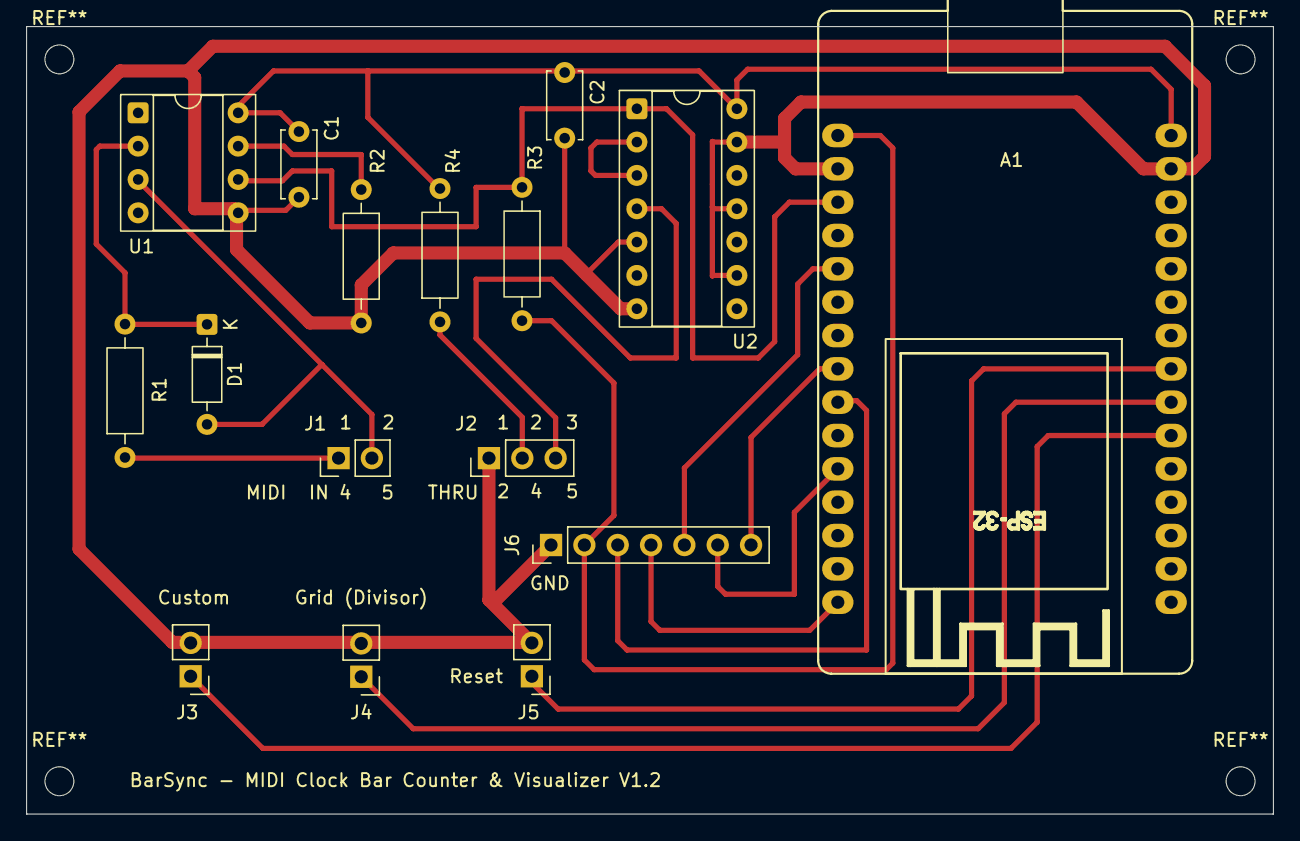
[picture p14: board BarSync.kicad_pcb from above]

Board: 2 copper layers, 95.0 x 60.0 mm, 16 parts (0 on the bottom side), 19 nets.

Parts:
A1: ESP32_DevKit_V1_DOIT_30GPIOs; DOIT_ESP32_DEVKIT_30Pins
C1, C2: 100n; C_Disc_D5.0mm_W2.5mm_P5.00mm
D1: 1N4148; D_DO-35_SOD27_P7.62mm_Horizontal
J1: MIDI; PinHeader_1x02_P2.54mm_Vertical
J2: THRU; PinHeader_1x03_P2.54mm_Vertical
J3: Custom; PinHeader_1x02_P2.54mm_Vertical
J4: Grid (Divisor); PinHeader_1x02_P2.54mm_Vertical
J5: Reset; PinHeader_1x02_P2.54mm_Vertical
J6: Connector; PinHeader_1x07_P2.54mm_Vertical
R1, R3, R4: 220; R_Axial_DIN0207_L6.3mm_D2.5mm_P10.16mm_Horizontal
R2: 4k7; R_Axial_DIN0207_L6.3mm_D2.5mm_P10.16mm_Horizontal
U1: 6N139; DIP-8_W7.62mm_Socket
U2: SN7406N; DIP-14_W7.62mm_Socket

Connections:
GND: A1.2 (GND), A1.29 (GND), C1.2, C2.2, J2.1, J3.2, J4.2, J5.2, J6.1 (PIN_1), R2.2, U1.5, U2.5, U2.7, U2.9, U2.11, U2.13
unnamed: A1.1 (3.3V), J6.2 (PIN_2), R3.2
unnamed: A1.21 (ADC1_CH4/D32), J3.1
unnamed: A1.22 (ADC1_CH5/D33), J4.1
unnamed: A1.5 (D4/ADC2_CH0), J6.5 (PIN_5)
unnamed: A1.8 (D5), J6.7 (PIN_7)
unnamed: A1.3 (D15/ADC2_CH3), R3.1, U1.6, U2.1
unnamed: A1.9 (D18), J6.3 (PIN_3)
unnamed: A1.11 (D21/SDA), J6.6 (PIN_6)
unnamed: A1.15 (D23), J6.4 (PIN_4)
unnamed: A1.23 (DAC1/ADC2_CH8/D25), J5.1
unnamed: A1.30 (VIN(+5V)), C1.1, C2.1, R4.2, U1.8, U2.14
unnamed: D1.2 (A), J1.2, U1.3
unnamed: D1.1 (K), R1.2, U1.2
unnamed: J1.1, R1.1
unnamed: J2.2, R4.1
unnamed: J2.3, U2.4
unnamed: R2.1, U1.7
unnamed: U2.2, U2.3

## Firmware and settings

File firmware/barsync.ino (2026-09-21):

/*
 * ============================================================================
 *  BARSYNC — MIDI Clock Bar Counter & Visualizer — ESP32 + SSD1309 OLED (SPI, 128x64)
 *  Version: 1.3.2
 * ============================================================================
 *
 * Counts incoming MIDI clock (24 PPQN), derives beat/bar from it, and shows
 * bar number, BPM, elapsed time, beat progress, and a multi-row divisor
 * progress grid (x1 to x64 bars) on a monochrome 128x64 OLED, in a
 * reduced "Elektron" style.
 *
 * Pattern Mode markers (up to 500, each pinned to a bar, one of 4
 * symbols) can be placed via OPERATION SETUP > SET MARKERS - see the
 * PATTERN MODE sections below. Two grid modes decide how the grid
 * shows them during normal playback (see gridMode, switched via
 * OPERATION SETUP > GRID MODE): CYCLING is the plain repeating divisor
 * grid; SCROLLING instead keeps the current bar fixed in the first
 * cell and scrolls markers in from the right as they approach, see
 * renderScrollingGrid(). Reset+Custom (held together) opens OPERATION
 * SETUP.
 *
 * REQUIRED LIBRARIES (Library Manager):
 *   - "MIDI Library" by Francois Best (FortySevenEffects)
 *   - "U8g2" by olikraus
 *
 * HARDWARE / PINOUT: see pinplan.md
 * CHANGE HISTORY: see CHANGELOG.md
 * ============================================================================
 */

#define FW_VERSION "1.3.2"

// Wird vom CI-Workflow beim Bauen ueber den Git-Tag gesetzt
// (-DBARSYNC_BUILD_TAG=...); bei einem lokalen Build in der Arduino IDE
// bleibt es beim Fallback "local".
#ifndef BARSYNC_BUILD_TAG
#define BARSYNC_BUILD_TAG "local"
#endif


#include <MIDI.h>
#include <U8g2lib.h>
#include <SPI.h>
#include <Preferences.h>
#include <WiFi.h>
#include "esp_sleep.h"
#include "driver/uart.h"
#include "driver/gpio.h"
#include <string.h> // memset() - used by factoryResetSettings()/factoryResetPatternMarkers()

// ---------------------------------------------------------------------------
// PIN DEFINITIONS
// ---------------------------------------------------------------------------
#define PIN_OLED_CS    5
#define PIN_OLED_DC    21
#define PIN_OLED_RESET 4
#define PIN_OLED_SCK   18
#define PIN_OLED_MOSI  23

#define PIN_MIDI_RX    15   // Hardware UART2 RX (GPIO16 not available on this board)
#define PIN_MIDI_TX    -1   // TX not required (MIDI-IN only)

#define PIN_BTN_DIVISOR 33
#define PIN_BTN_CUSTOM  32
#define PIN_BTN_RESET   25

// ---------------------------------------------------------------------------
// DISPLAY (SSD1309, Hardware-SPI)
// ---------------------------------------------------------------------------
U8G2_SSD1309_128X64_NONAME0_F_4W_HW_SPI u8g2(
    U8G2_R0, PIN_OLED_CS, PIN_OLED_DC, PIN_OLED_RESET);

// ---------------------------------------------------------------------------
// MIDI (Hardware-Serial2 on the ESP32)
// ---------------------------------------------------------------------------
HardwareSerial MidiSerial(2);
MIDI_CREATE_INSTANCE(HardwareSerial, MidiSerial, MIDI);

// ---------------------------------------------------------------------------
// STATE — Clock / Bar / Beat
// ---------------------------------------------------------------------------
volatile uint32_t totalTicks   = 0;   // since start, runs "forever"
volatile uint16_t tickInBeat   = 0;   // 0..23
volatile uint16_t currentBeat  = 0;   // 0..(beatsPerBar-1)
volatile uint32_t currentBar   = 0;   // absolute bar number (0-based internally)
volatile bool     isRunning    = false;

// Clock watchdog: timestamp of the last received clock tick (in ms).
// Used to detect when the MIDI clock is "lost"
// (e.g. cable unplugged, source stopped without sending a Stop message).
volatile uint32_t lastClockTickMillis = 0;
const uint32_t    CLOCK_LOST_TIMEOUT_MS = 5000;

// ---------------------------------------------------------------------------
// STANDBY / LIGHT SLEEP
// ---------------------------------------------------------------------------
const uint32_t STANDBY_COUNTDOWN_MS = 10000; // show countdown 10s ahead (independent of chosen delay)

// Prevents a button that woke the ESP32 from standby
// from also triggering its normal function on release.
bool suppressDivisorAction = false;
bool suppressCustomAction = false;
bool suppressResetAction   = false;

// time signature: counter values (denominator is only carried along for the display)
const uint8_t  TIME_SIG_NUM[]   = {4, 3, 5, 6, 7};
const char*    TIME_SIG_LABEL[] = {"4/4", "3/4", "5/4", "6/8", "7/8"};
const uint8_t  TIME_SIG_COUNT   = 5;
uint8_t timeSigIndex = 0; // index into the array above
uint8_t beatsPerBar()  { return TIME_SIG_NUM[timeSigIndex]; }

// Divisor (bars per progress cycle)
const uint8_t DIVISOR_VALUES[] = {1, 2, 4, 8, 16, 32, 64, 128};
const uint8_t DIVISOR_COUNT    = 8;
uint8_t divisorIndex = 2; // starts at x4 (index freely selectable)
uint8_t divisor()      { return DIVISOR_VALUES[divisorIndex]; }

// ---------------------------------------------------------------------------
// settings (persistent in the Flash via Preferences/NVS)
// ---------------------------------------------------------------------------
Preferences prefs;

// Custom button role (Switches > Custom): which fixed function the
// custom button performs on a normal short press. Default: SET 1.1
// (instant re-anchor - see triggerSet11()).
enum CustomRole { CUSTOM_ROLE_TIMESIG = 0, CUSTOM_ROLE_SET11 = 1 };
const uint8_t CUSTOM_ROLE_COUNT = 2;
const char* CUSTOM_ROLE_LABEL[] = {"TIMESIG", "SET 1.1"};

struct Settings {
  uint8_t timeSigIndex;
  uint8_t divisorIndex;
  uint8_t contrast;
  bool    invert;       // true color inversion (controller command)
  uint8_t enabledDivisorMask; // bit i = divisor i selectable
  bool    standbyEnabled;
  uint8_t standbyDelayIndex; // index into STANDBY_DELAY_MINUTES
  uint8_t customButtonRole;  // one of the CustomRole values above (Switches > Custom)
  uint8_t enabledTimeSigMask; // bit i = time signature i selectable for the
                               // custom button's TIMESIG role to cycle through
                               // (Switches > Custom > Function=TIMESIG > Timesigs).
                               // Does NOT affect the fixed value on page 1
                               // (SETUP > TIMESIG), which always cycles through
                               // all of them.
  bool    resetInstantMode;  // Only affects SET 1.1 (Custom button role) - Reset 1
                              // and Reset 2 (physical reset button only, it's no
                              // longer a custom-button role) are unaffected by
                              // this and always just wait for the next bar/cycle
                              // end, exactly like before any of this existed.
                              // false (default) = QUANTIZED: SET 1.1's new anchor
                              // is rounded down to the nearest already-existing
                              // beat boundary (realigns with the sequencer's own
                              // beat pattern without changing its phase); true =
                              // INSTANT: SET 1.1 uses the raw current tick as-is,
                              // spinning up a brand new phase - see triggerSet11().
                              // Menu: Switches > Custom > Function=SET 1.1 > Mode
  bool    reset1PlaytimeEnabled; // whether Reset 1 (physical button, short
                                  // press) also resets the elapsed play time.
                                  // The bar counter/grid always resets
                                  // unconditionally for Reset 1 - only the
                                  // play time is optional. Does not affect
                                  // SET 1.1, which always resets everything.
                                  // Menu: Switches > Reset Switch > Reset 1
  bool    reset2PlaytimeEnabled; // same as above, for Reset 2 (physical
                                  // button, held past 1s) - independent
                                  // setting, not shared with Reset 1.
                                  // Menu: Switches > Reset Switch > Reset 2
  bool    gridSeparatorsEnabled; // true (default): 32-bar group separators
                                  // in the divisor grid (x16/x32/x64/x128),
                                  // shared 35px reference footprint. false:
                                  // original layout, fixed 32px, no grouping.
                                  // Menu: Display > Grid Lines
};
Settings settings;

const uint8_t CONTRAST_STEPS[] = {25, 50, 100, 150, 200, 255};
const uint8_t CONTRAST_STEP_COUNT = 6;

const uint16_t STANDBY_DELAY_MINUTES[] = {1, 5, 10, 30, 60};
const uint8_t  STANDBY_DELAY_COUNT = 5;
uint32_t getStandbyTimeoutMs() {
  return (uint32_t)STANDBY_DELAY_MINUTES[settings.standbyDelayIndex] * 60000UL;
}

bool isDivisorEnabled(uint8_t i) { return (settings.enabledDivisorMask >> i) & 0x01; }

uint8_t countEnabledDivisor() {
  uint8_t c = 0;
  for (uint8_t i = 0; i < DIVISOR_COUNT; i++) if (isDivisorEnabled(i)) c++;
  return c;
}

// Find the next enabled index (wrap-around), for normal
// cycling via button during operation.
uint8_t nextEnabledDivisor(uint8_t current) {
  uint8_t idx = current;
  for (uint8_t i = 0; i < DIVISOR_COUNT; i++) {
    idx = (idx + 1) % DIVISOR_COUNT;
    if (isDivisorEnabled(idx)) return idx;
  }
  return current;
}

// Same as nextEnabledDivisor() above, but only considers values within
// [minValue, maxValue] - used while SCROLLING grid mode is active,
// which only ever shows meaningfully at 2/4/8/16 (see
// onDivisorButton()) - 1 is excluded since a 1-bar window can't show
// any "scrolling ahead" at all, and above 16 the marker symbols
// wouldn't fit legibly (see SCROLLING_MAX_WINDOW_BARS).
uint8_t nextEnabledDivisorInRange(uint8_t current, uint8_t minValue, uint8_t maxValue) {
  uint8_t idx = current;
  for (uint8_t i = 0; i < DIVISOR_COUNT; i++) {
    idx = (idx + 1) % DIVISOR_COUNT;
    if (isDivisorEnabled(idx) && DIVISOR_VALUES[idx] >= minValue && DIVISOR_VALUES[idx] <= maxValue) return idx;
  }
  return current;
}

// Highest enabled divisor at or below 16 (DIVISOR_VALUES indices for
// 16,8,4,2, in that preference order) - used to initialize a sensible
// window size the moment SCROLLING mode is switched on (see
// onSetupMenuChange()'s GRID MODE row), same reasoning as
// nextEnabledDivisorInRange() above for why 1 is never a candidate.
uint8_t highestEnabledDivisorUpTo16() {
  for (int8_t i = 4; i >= 1; i--) { // DIVISOR_VALUES indices 4,3,2,1 = 16,8,4,2
    if (isDivisorEnabled(i)) return i;
  }
  return divisorIndex; // none of 2/4/8/16 enabled - leave unchanged, defensive
}

bool isTimeSigEnabled(uint8_t i) { return (settings.enabledTimeSigMask >> i) & 0x01; }

uint8_t countEnabledTimeSig() {
  uint8_t c = 0;
  for (uint8_t i = 0; i < TIME_SIG_COUNT; i++) if (isTimeSigEnabled(i)) c++;
  return c;
}

// Find the next enabled time signature (wrap-around) - only used for
// the custom button's TIMESIG role (Switches > Custom); the fixed
// value on page 1 (SETUP > TIMESIG) always cycles through all of them
// regardless of this mask.
uint8_t nextEnabledTimeSig(uint8_t current) {
  uint8_t idx = current;
  for (uint8_t i = 0; i < TIME_SIG_COUNT; i++) {
    idx = (idx + 1) % TIME_SIG_COUNT;
    if (isTimeSigEnabled(idx)) return idx;
  }
  return current;
}

void loadSettings() {
  prefs.begin("midiclock", true);
  settings.timeSigIndex = prefs.getUChar("tsig", 0);
  settings.divisorIndex = prefs.getUChar("div", 2);
  settings.contrast     = prefs.getUChar("contrast", 50);
  settings.invert       = prefs.getBool("invert", false);
  settings.enabledDivisorMask = prefs.getUChar("divmask", 0xFC); // default: x4-x128 only, matches the Eurorack sibling
  settings.standbyEnabled     = prefs.getBool("stbyon", true);
  settings.standbyDelayIndex  = prefs.getUChar("stbydelay", 1); // default 5 min
  settings.customButtonRole   = prefs.getUChar("customrole", CUSTOM_ROLE_SET11);
  settings.enabledTimeSigMask = prefs.getUChar("tsigmask", 0xFF);
  settings.resetInstantMode   = prefs.getBool("rstinstant", false); // default: QUANTIZED
  settings.reset1PlaytimeEnabled = prefs.getBool("r1playtime", true);
  settings.reset2PlaytimeEnabled = prefs.getBool("r2playtime", true);
  settings.gridSeparatorsEnabled = prefs.getBool("gridseps", true);
  prefs.end();

  // Apply loaded values to the active runtime variables
  if (settings.timeSigIndex >= TIME_SIG_COUNT) settings.timeSigIndex = 0;
  if (settings.divisorIndex >= DIVISOR_COUNT)  settings.divisorIndex = 2;
  if (countEnabledDivisor() == 0) settings.enabledDivisorMask = 0xFF;
  if (settings.standbyDelayIndex >= STANDBY_DELAY_COUNT) settings.standbyDelayIndex = 1;
  if (settings.customButtonRole >= CUSTOM_ROLE_COUNT) settings.customButtonRole = CUSTOM_ROLE_SET11;
  if (countEnabledTimeSig() == 0) settings.enabledTimeSigMask = 0xFF; // safety net
  timeSigIndex = settings.timeSigIndex;
  divisorIndex = settings.divisorIndex;
}
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
void loop() {
  // Drain all pending MIDI bytes, not just one: if something earlier
  // in this loop() (most notably renderAnalyzer()'s SPI framebuffer
  // push) takes a few ms, one or more clock bytes can pile up in the
  // UART's hardware FIFO in the meantime. Reading only one per
  // iteration would then process them late and unevenly - a slow
  // display update must never delay clock processing more than
  // necessary.
  while (MIDI.read()) {}

  updateButton(btnDivisor, onDivisorButton);
  updateButton(btnCustom,  onCustomButton);
  updateButton(btnReset,   onResetButton);

  // Nudge mode: custom button+divisor simultaneously -> in and out
  // (toggle, same combo), now with the same 1s hold-to-confirm as the
  // Operation Setup entry/exit combo below - see nudgeComboHoldActive and
  // drawHoldSweep() in render(). Uses the already-debounced stableState
  // values of the buttons (same debouncing as normal time signature/
  // divisor selection). "armed" flag prevents a still-held combo
  // press from immediately counting as exit again - both buttons must
  // be fully released before the combo can trigger again ("press again").
  // Disabled entirely while the Pattern Mode paint editor is active
  // (patternEditActive) - Custom+Divisor there is already the
  // instant, non-hold tool-cycle chord (see loop() further down), so
  // this slower 1s-hold combo (and its sweep) must never also apply.
  static bool    nudgeComboArmed = true;
  static uint8_t nudgeSoloButton = 0; // 0=none, 1=custom, 2=divisor (currently held alone)
  {
    bool customDown = (btnCustom.stableState == LOW);
    bool divDown   = (btnDivisor.stableState == LOW);
    bool comboNow  = customDown && divDown;

    bool comboEligible = comboNow && nudgeComboArmed && !patternEditActive &&
                         (currentMode == MODE_NORMAL || currentMode == MODE_NUDGE);
    if (comboEligible) {
      if (!nudgeComboHoldActive) {
        nudgeComboHoldActive  = true;
        nudgeComboHoldStartMs = millis();
      }
      // Sweep counts as SEEN once actually drawn (same grace period
      // drawHoldSweep() itself waits out).
      if (millis() - nudgeComboHoldStartMs >= HOLD_SWEEP_GRACE_MS) {
        customNudgeSweepSeen  = true;
        divisorNudgeSweepSeen = true;
      }
      if (millis() - nudgeComboHoldStartMs >= 1000) {
        currentMode = (currentMode == MODE_NORMAL) ? MODE_NUDGE : MODE_NORMAL;
        if (currentMode == MODE_NUDGE) nudgeOffsetSixteenths = 0;
        suppressCustomAction = true;
        suppressDivisorAction = true;
        nudgeComboArmed = false;
        nudgeComboHoldActive = false;
        nudgeSoloButton = 0; // discard any ongoing solo detection
      }
    } else {
      nudgeComboHoldActive = false;
    }
    if (!customDown && !divDown) {
      nudgeComboArmed = true; // both released -> combo armed again
    }
    // Cleared per-button on release so an earlier aborted attempt
    // can't bleed into a later, unrelated solo press.
    if (!customDown) customNudgeSweepSeen  = false;
    if (!divDown)    divisorNudgeSweepSeen = false;

    // Single nudge step: triggered only on release (no auto-repeat
    // while held). "nudgeComboArmed" as an extra condition prevents a
    // not-yet-fully-released combo remnant (one finger still lingers)
    // from incorrectly counting as a new solo press.
    if (currentMode == MODE_NUDGE) {
      if (comboNow) {
        nudgeSoloButton = 0;
      } else if (customDown && !divDown) {
        if (nudgeSoloButton == 0 && nudgeComboArmed) nudgeSoloButton = 1;
      } else if (divDown && !customDown) {
        if (nudgeSoloButton == 0 && nudgeComboArmed) nudgeSoloButton = 2;
      } else if (nudgeSoloButton != 0) {
        doNudge(nudgeSoloButton == 1 ? -6 : +6);
        nudgeSoloButton = 0;
      }
    } else {
      nudgeSoloButton = 0;
    }
  }

  // Operation Setup entry / Pattern Edit exit: Custom+Reset held
  // together (same idea as the Nudge combo, different button pair).
  // isSimultaneousChord matters inside the paint editor specifically:
  // holding Reset while tapping Custom/Divisor to paint is normal
  // there, so "both down" alone can't mean exit - presses must have
  // started close together in time. Once detected, both must stay
  // held a further 1s (leaveComboHoldActive) with a "LEAVE" sweep.
  static bool operationSetupComboArmed = true;
  {
    bool customDown = (btnCustom.stableState == LOW);
    bool resetDown  = (btnReset.stableState == LOW);
    bool isSimultaneousChord = isChordTiming(btnCustom.pressStartMs, btnReset.pressStartMs);
    if (customDown && resetDown && operationSetupComboArmed && isSimultaneousChord) {
      if (!leaveComboHoldActive) {
        leaveComboHoldActive  = true;
        leaveComboHoldStartMs = millis();
      }
      // Sweep counts as SEEN once actually drawn, not just once the
      // chord condition became true.
      if (millis() - leaveComboHoldStartMs >= HOLD_SWEEP_GRACE_MS) {
        customComboSweepSeen = true;
        resetComboSweepSeen  = true;
      }
      if (millis() - leaveComboHoldStartMs >= 1000) {
        operationSetupComboArmed  = false;
        leaveComboHoldActive = false;
        if (patternEditActive) {
          // Not a fresh entry from the main screen, so the one-time
          // info screens don't get re-armed - see
          // runOperationSetupMenu().
          patternEditActive = false;
          savePatternMarkers();
          runOperationSetupMenu(false);
        } else if (currentMode == MODE_NORMAL) {
          runOperationSetupMenu(); // blocking, see there
        }
      }
    } else {
      leaveComboHoldActive = false;
    }
    if (!customDown && !resetDown) {
      operationSetupComboArmed = true;
    }
    // Cleared per-button on release so an earlier aborted attempt
    // can't bleed into a later, unrelated solo press.
    if (!customDown) customComboSweepSeen = false;
    if (!resetDown)  resetComboSweepSeen  = false;
  }

  // Detect the reset button's escalation threshold (Reset 1 -> Reset
  // 2) already while held, not just on release. Uses its own
  // RESET2_HOLD_MS (2s) instead of the generic LONGPRESS_MS, which is
  // still used unchanged for the custom button and menu navigation.
  if (btnReset.isPressed) {
    uint32_t heldMs = millis() - btnReset.pressStartMs;
    if (!resetLongAlreadyHandled && heldMs >= RESET2_HOLD_MS) {
      onResetMediumHeldDuringPress();
      resetLongAlreadyHandled = true;
    }
  } else {
    resetLongAlreadyHandled = false;
  }

  // Detect long press of the custom button already while held
  // -> toggles the MIDI analyzer (in both directions).
  if (btnCustom.isPressed) {
    if (!customLongAlreadyHandled && (millis() - btnCustom.pressStartMs) >= LONGPRESS_MS) {
      onCustomButtonLongHeldDuringPress();
      customLongAlreadyHandled = true;
    }
    // Mirrors render()'s own condition for drawing the solo "MIDI
    // MONITOR" sweep, so this only goes true when the user actually saw it.
    bool soloSweepEligible = !patternEditActive && currentMode == MODE_NORMAL &&
                             !btnDivisor.isPressed && !btnReset.isPressed && !customLongAlreadyHandled;
    if (soloSweepEligible && (millis() - btnCustom.pressStartMs) >= HOLD_SWEEP_GRACE_MS) {
      customSoloSweepSeen = true;
    }
  } else {
    customLongAlreadyHandled = false;
    customSoloSweepSeen      = false;
  }

  // Pattern Mode marker editor fast-scroll: unlike the one-shot
  // trigger above, these run every iteration for as long as the
  // button stays held, so they can keep paging every
  // PATTERN_EDIT_FAST_SCROLL_MS rather than firing once.
  onCustomHeldDuringPress();
  onDivisorHeldDuringPress();

  // Pattern Mode paint-on-hold: the moment Reset goes down (not on
  // release, and not tied to any navigation) immediately paints/erases
  // the bar the cursor is already sitting on - so holding Reset and
  // then moving continues painting from where you already are, rather
  // than only starting once you move to a new bar. Edge-triggered via
  // its own static, since btnReset.isPressed itself stays true for the
  // whole hold and would otherwise repaint the same bar every
  // iteration for no reason.
  {
    static bool resetWasPressedInPatternEdit = false;
    if (patternEditActive && btnReset.isPressed && !resetWasPressedInPatternEdit) {
      paintPatternMarkerAtCursor();
    }
    resetWasPressedInPatternEdit = patternEditActive && btnReset.isPressed;
  }
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

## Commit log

2026-09-04 Firmware V1.2
    [BarSync-B_Cu.gbr, BarSync-B_Mask.gbr, BarSync-B_Paste.gbr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]
2026-09-05 FIrmware 1.2
    [BarSync-B_Cu.gbr, BarSync-B_Mask.gbr, BarSync-B_Paste.gbr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]
2026-09-05 Hardware V1.2
    [BarSync_BOM.csv, BarSync_BOM.en.csv]
2026-09-06 Documentation Update
    [BarSync_Inserts_Inverted_V1.2.3mf]
2026-09-07 Color Order
    [BarSync_Inserts_Inverted_V1.2.3mf, BarSync_Inserts_V1.2.3mf]
2026-09-21 Add automated firmware build + browser-based flash page
    - .github/workflows/build-firmware.yml: builds firmware/barsync.ino via
    arduino-cli on version tags, merges bootloader/partitions/app into a
    single binary and attaches it to the GitHub Release
    - docs/flash/: bilingual (DE/EN) ESP Web Tools flash page, always
    installs the latest released firmware via WebSerial in the browser
2026-09-21 Fix CI: arduino-cli requires sketch folder to match .ino filename
    barsync.ino lives in firmware/, but arduino-cli's sketch convention
    expects <folder>/<folder>.ino. Copy into a correctly named temp
    folder before compiling instead of restructuring the repo.
2026-09-21 Add build-tag traceability + fix flash-page logo
    - firmware/barsync.ino: BARSYNC_BUILD_TAG (default "local") printed
    alongside FW_VERSION over Serial, so a flashed device can be traced
    back to the exact git tag/CI build that produced it
    - .github/workflows: inject the tag as BARSYNC_BUILD_TAG via
    --build-property at compile time
    - docs/images/BarSync_logo_white.svg: copy of the repo-root logo so it
    is actually inside the published GitHub Pages root (docs/); fixed
    the flash page's broken image path accordingly
    [barsync.ino]
2026-09-21 Show which firmware version the flash page will install
    CI now writes the real FW_VERSION + build tag into manifest.json's
    version field instead of the placeholder "auto". The page fetches
    that and displays it above the install button (DE/EN), so it's clear
    what's about to be flashed before clicking Install.
2026-09-21 Fix stale version display: cache-bust the manifest.json fetch
    Browser/CDN caching meant both ESP Web Tools' install dialog and our
    own version line kept showing an old manifest.json (still 'auto')
    even after CI published a fresh one. Append a per-load timestamp
    query param and fetch with cache: 'no-store' so it's always current.
2026-09-21 Pin toolchain versions instead of always installing latest
    Pinned to what the last known-good CI run actually resolved:
    esp32:esp32@3.3.12, MIDI Library@5.0.2, U8g2@2.36.19. Protects future
    builds from breaking on an unannounced upstream core/library update;
    bump these deliberately when there's a reason to.
2026-09-21 README: split firmware flashing into web flasher + manual (DE/EN)
    Promotes the browser-based flasher as the primary path, links the
    manual Arduino IDE route to the existing step-by-step Chapter 8 in
    the Aufbauanleitung/Assembly Guide instead of duplicating it.
2026-09-28 BOM: Update
    [BarSync_BOM.csv, BarSync_BOM.en.csv, BarSync_Reichelt.csv]
